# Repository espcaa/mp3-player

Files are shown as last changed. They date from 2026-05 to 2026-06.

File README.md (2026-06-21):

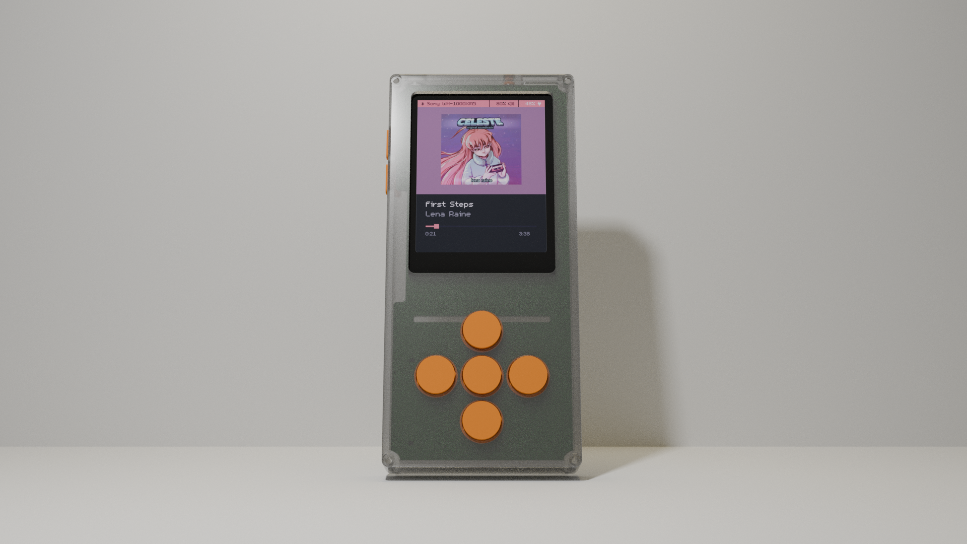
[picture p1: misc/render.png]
render


[{BOM}](https://github.com/espcaa/mp3-player/blob/main/BOM.md) - [{JOURNAL}](https://github.com/espcaa/mp3-player/blob/main/JOURNAL.md) - [{PCB}](https://kicanvas.org/?repo=https%3A%2F%2Fgithub.com%2Fespcaa%2Fmp3-player%2Ftree%2Fmain%2Fsrc%2Fkicad) - [{FIRMWARE}](https://github.com/espcaa/mp3-player/blob/main/src/firmware) - [{CAD}](https://cad.onshape.com/documents/df238a6328d0735d97863cef/w/6197d36ae28a3603accb47f3/e/8dee80f336b142ce4e5ee150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)

# mp3-player

A minimalist open source pocket sized¹ mp3 player\
\
(¹ if your pocket is big enough to fit a 115mmx50mmx20mm brick)

## Why did I even build this?

I bring my phone every time, everywhere I go. My main excuse is that I need it for music, but that's not usually what ends up happening... So I built this to have a dedicated music player that I could bring with me when I don't need a phone! (mainly high school or going for a walk)\
I also wanted to learn how to design a more complex & integrated pcb!\
\
If you find this cool, you should read [the journal](https://github.com/espcaa/mp3-player/blob/main/JOURNAL.md) I kept while designing this!

## Overview

**Specs**:

- mcu: rp2350b
- bluetooth module: fsc-BT1114QI
- dac: PCM5102A
- power: 505050 battery + BQ24075 power path ic
- pcb: 4 layer (signal, ground, power, signal) 115mmx50mm
- case: 3d printed

**Features**:

- full size sdcard slot
- 2.8 inch high definition color display (480x640, around 286 dpi)
- custom themes
- 3.5mm headphone jack
- bluetooth le + classic support
- modern and clean ui

## Hardware

<p>
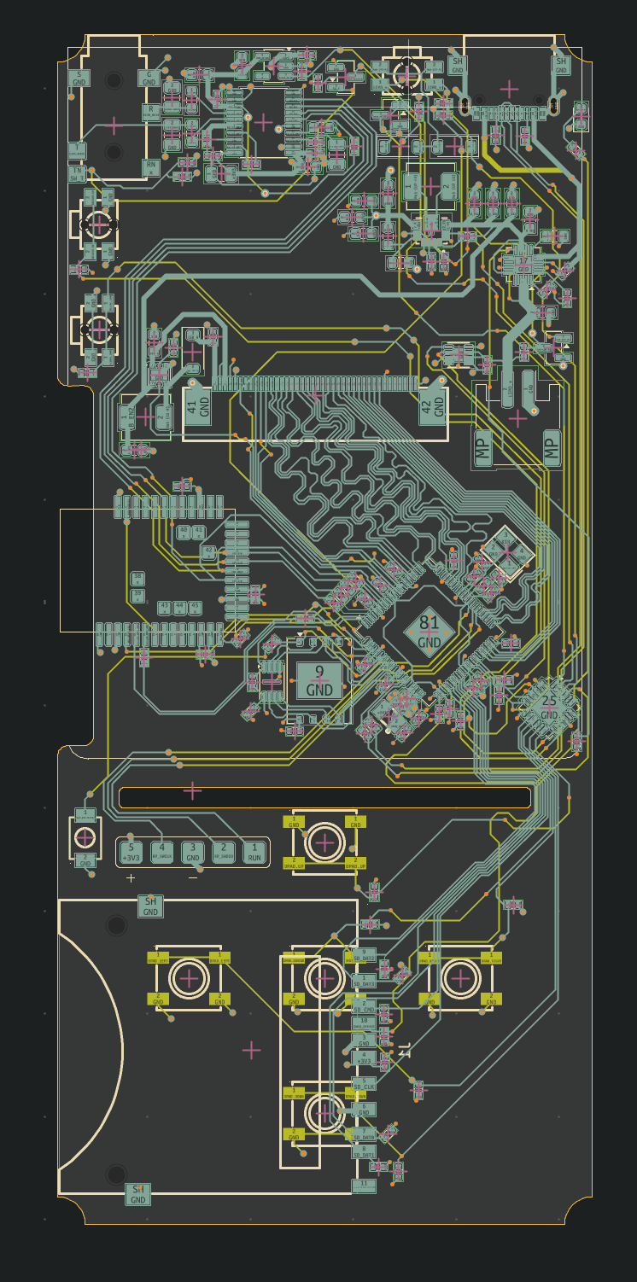
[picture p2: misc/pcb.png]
pcb
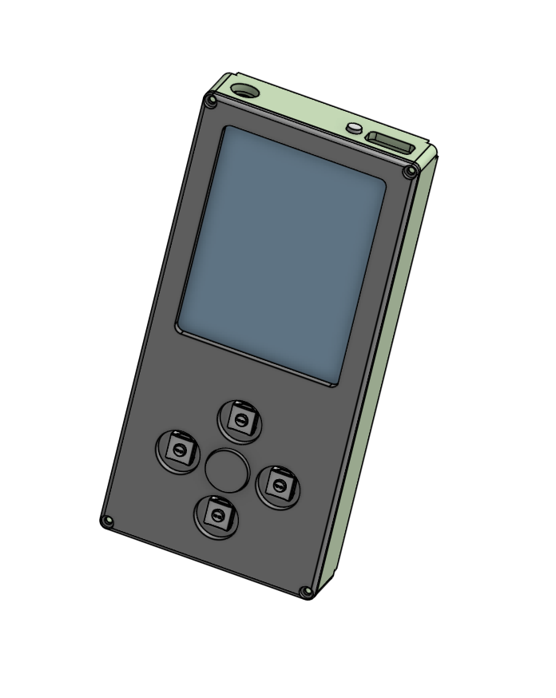
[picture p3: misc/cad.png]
cad

</p>

_pcb & cad screenshots_
\
\
The brain is a 4 layer hand routed pcb, designed to be compact & cheap to manufacture (jlcpcb 4 layers basic tolerances).\
I first planned to use a nrf chip for the audio but finally moved to a feasycom module to support classic A2DP bluetooth audio (basically everything that is not recent/high end) because I realized my headphones were not le compatible (but now my new ones are!).\
Full size sdcard support is because I wanted to be able to use my mac's sdcard reader to easily transfer new music + not lose super small micro sd cards.\
I also originally wanted to make the case in transparent resin, but I ended up choosing 3d printing for multiple reasons:

- way cheaper
- faster to iterate on
- petg is way more shock resistant than resin
- faster to get a finished project

[explore the board & schematics in your browser](https://kicanvas.org/?repo=https%3A%2F%2Fgithub.com%2Fespcaa%2Fmp3-player%2Ftree%2Fmain%2Fsrc%2Fkicad)

## Firmware

_warning: this is a wip and some parts of the firmware have been ai generated to get a poc working quickly, but I plan to rewrite it very soon._ \
\
The firmware is written in c and uses the pico sdk. I also wrote a desktop simulator that allows you to test ui changes without reflashing all the time/having the device.

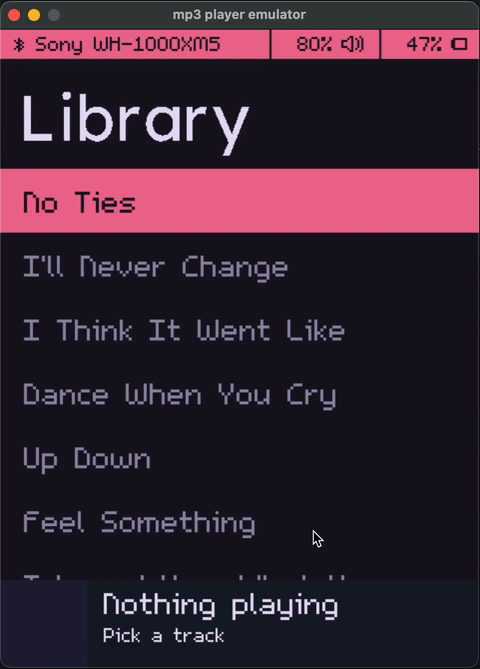
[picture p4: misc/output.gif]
firmware


**Building to run on device:**

_If you just need an already built uf2, you can just grab it from the releases page or directly from the actions tab (action runs on every commit inside src/firmware)_
\
\
(You need cmake, a pico sdk, an arm-none-eabi toolchain, pico-extras installed)

- clone this repo
- export these env vars:
  - `PICO_SDK_PATH` -> path to pico-sdk
  - `PICO_TOOLCHAIN_PATH` -> path to an arm-none-eabi toolchain (`Applications/ArmGNUToolchain/15.2.rel1/arm-none-eabi/bin` on my laptop)
  - `PICO_EXTRAS_PATH` -> path to pico-extras
- go to src/firmware/ & run `./build_pico.sh --clean`
- flash the uf2 via usb (hold BOOTSEL while plugging in the device, then drag the uf2 to the mounted drive)

**Building to run on desktop:**

_(this allows you to run/test the same ui on your computer without flashing the device!)_\
_(you need sdl2 installed)_

- go to src/firmware/ & run `./run_emulator.sh --clean`

## License

Firmware is MIT, hardware is CERN-OHL-S, and the 3d files + docs are CC-BY-SA.\
See [LICENSE](LICENSE) for details.\
\
\
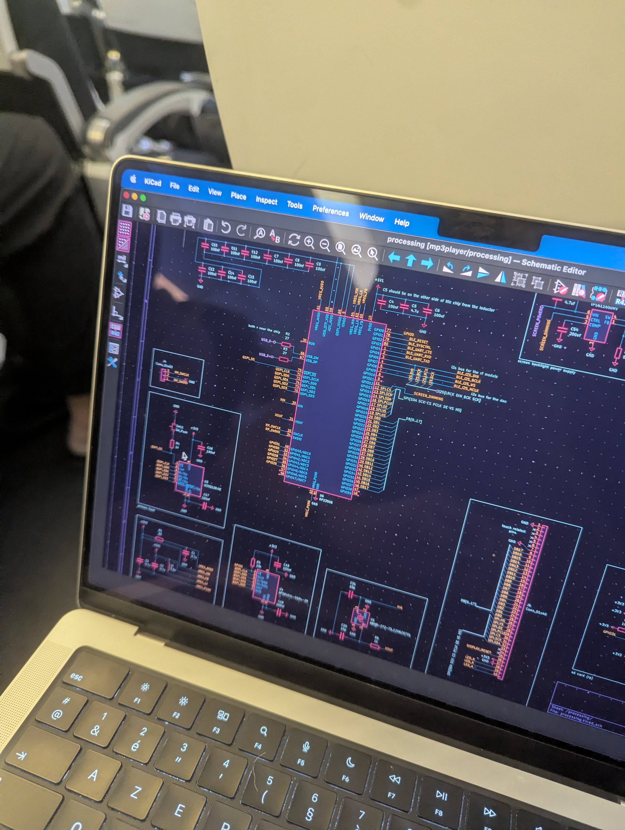
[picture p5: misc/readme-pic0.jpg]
readme-pic0

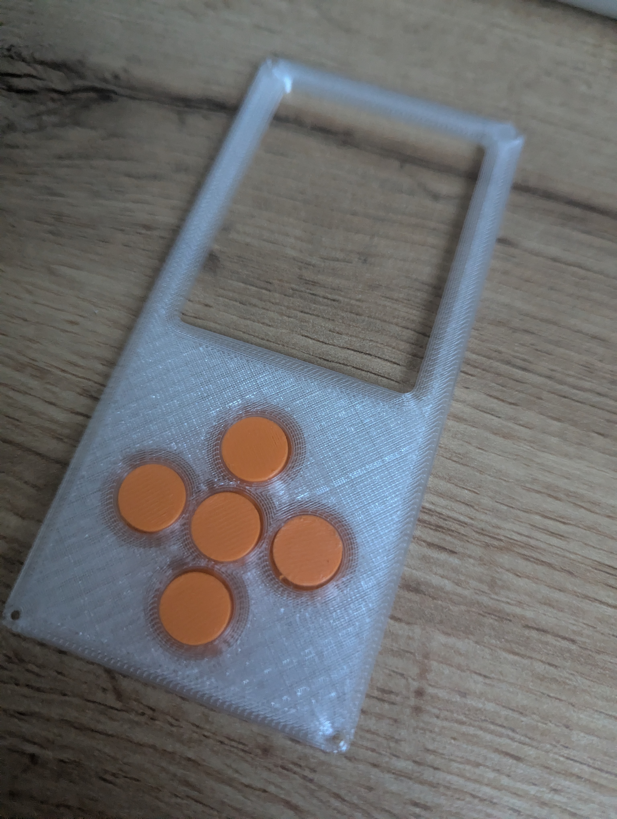
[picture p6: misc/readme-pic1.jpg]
readme-pic1

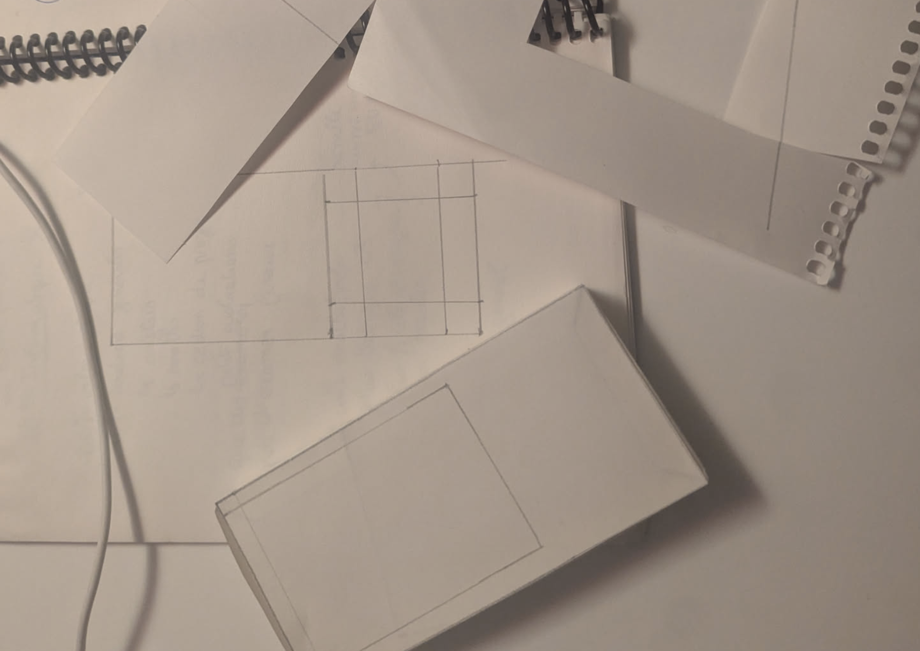
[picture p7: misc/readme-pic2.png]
readme-pic2

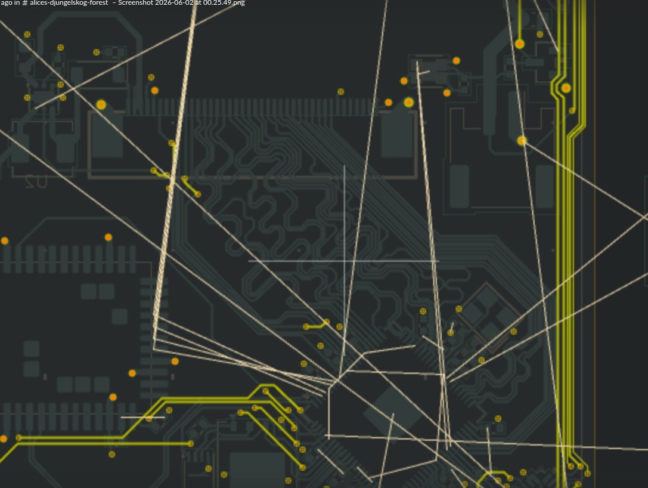
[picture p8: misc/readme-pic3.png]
readme-pic3

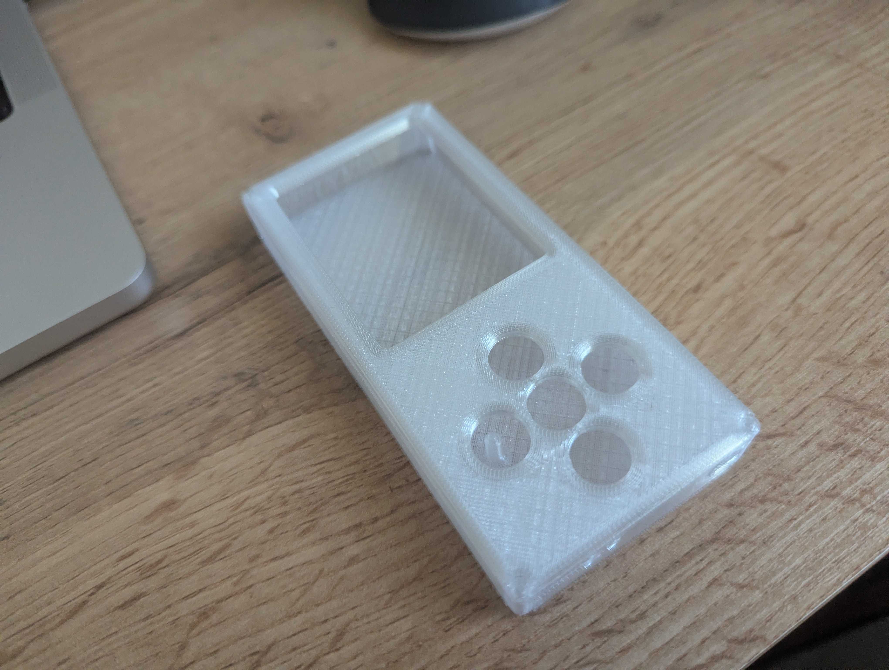
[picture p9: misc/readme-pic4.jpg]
readme-pic4


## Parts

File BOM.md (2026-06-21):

| Item | Quantity | Note/Desc | Price  | Total  |
| --- | --- | --- | --- | --- |
| 3d printed case  | 1 | PETG+PLA at $20/kg (bambulab prices) | $1 | $1 |
| pcb | 1 | jlcpcb 4 layers white + stencil (delivery to france) | $64.75 | $64.75 |
| pcb components | 1 | lcsc order (delivery to france) | $60.13 | $60.13 |
| bluetooth module | 1 | feasycom fsc-bt1114qi | $19.89 | $7.5 |
| battery | 1 | 505050 li-ion | $10.58 | $10.58 |
| screen | 1 | 2.8 inch 480x640 tft display | $15.63 | $15.63 |
| jst connectors | 1 | random aliexpress kit, only needed if your battery doesn't come with one | $1 | $1 |
| m2 1.6cm screw | 4 | // | $0.1 | $0.4 |
| m2 nut | 4 | // | $0.1 | $0.4 |
| rp2350b | 2 | only needed because lcsc doesn't have rp2350b in stock right now | $0.5 | $13.77 |

Total: around 175 usd\
\
**Specific components:**

- bluetooth module: [fsc-bt1114qi](https://www.feasycom.com/product/fsc-bt1114qi/)
- screen: [gooddisplay 2.8 inch 480x640 tft](https://www.buydisplay.com/bar-type-2-8-inch-480x640-ips-tft-lcd-display-spi-rgb-interface)

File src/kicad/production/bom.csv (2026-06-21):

Designator | Footprint | Quantity | Value | LCSC Part #
C1, C3, C5 | 0402 | 3 | 4.7u | C23733
C10, C11, C12, C13, C14, C15, C16, C19, C22, C27, C32, C4, C43, C44, C46, C47, C51, C56, C6, C7, C8, C9 | 0402 | 22 | 100nf | C1525
C2 | 0402 | 1 | 4.7u | C368809
C20, C21 | 0402 | 2 | 15p | C1548
C23, C45, C48 | 0402 | 3 | 2.2uf | C12530
C24, C25, C29, C42, C55 | 0402 | 5 | 1uf | C307427
C26, C31, C33, C37, C38, C49, C50 | 0603 | 7 | 10uf | C96446
C28, C30, C41, C53 | 0603 | 4 | 4.7uf | C19666
C34, C35, C36 | 0603 | 3 | 22uf | C59461
C39, C40 | 0805 | 2 | 2.2nf | C28260
C52, C57 | 0805 | 2 | 10uf | C1713
C54 | 0402 | 1 | 200nf | C16772
D1 | D_SOD-123 | 1 | MBR0540T1G | C21353
D2, D3 | D_SOD-123 | 2 | D_Schottky | C8598
D4 | 0603 | 1 | LED | C2286
J1 | SD-SMD_SD-006M | 1 | SD_Card_Receptacle | C125615
J2 | USB-C-SMD_GT-USB-7047C | 1 | USB_C_Receptacle_USB2.0_16P | C963218
J5 | JST_PH_S2B-PH-SM4-TB_1x02-1MP_P2.00mm_Horizontal | 1 | Conn_01x02 | C295747
J6 | FPC-SMD_AFC07-S40FCC00 | 1 | Conn_01x42 | C11062
J7 | AUDIO-SMD_PJ-342-141 | 1 | AudioJack3_Ground_SwitchTR | C7507452
L1 | IND-SMD_L2.0-W1.6_AOTA-B201610S3R3-101-T | 1 | 3.3u | C42411119
L2 | L_Sunlord_MWSA0402S | 1 | 1.5uh | C351088
L3 | L_TechFuse_SL0420 | 1 | 10uh | C22463809
Q2, Q3, Q4 | SOT-23 | 3 | BSS138 | C52895
R1, R32, R33, R38, R48, R49, R50 | 0402 | 7 | 33 | C2906931
R10, R11, R12, R17, R18, R22, R25, R27, R28, R29, R31, R35, R39, R40, R41, R42, R43, R44, R45, R46, R47, R5, R7, R8, R9 | 0402 | 25 | 10k | C2906861
R13, R14 | 0402 | 2 | 5.1k | C852856
R15 | 0603 | 1 | 820 | C23253
R16, R4, R6 | 0402 | 3 | 1k | C852624
R19, R26, R30 | 0402 | 3 | 100k | C481918
R2, R3 | 0402 | 2 | 27 | C25105
R20 | 0603 | 1 | 470k | C2907040
R21 | 0603 | 1 | 150k | C326734
R23, R24 | 0603 | 2 | 470 | C218042
R34 | 0603 | 1 | 6.8 | C2907056
R36, R37 | 0402 | 2 | 4.7k | C2906941
R51 | 0402 | 1 | 330 | C71626
SW1, SW10, SW7 | KEY-SMD_4P-L4.7-W3.5-P1.70-LS6.4-EH | 3 | EVQPUL02K | C79175
SW11 | SW-SMD_L3.9-W3.0-P4.45 | 1 | TS-1088-AR02016 | C720477
SW3, SW4, SW5, SW8, SW9 | SW-SMD_4P-L6.2-W6.2-P4.00-LS6.8 | 5 | SW_Push | C115354
U1 | CRYSTAL-SMD_4P-L3.2-W2.5-BL | 1 | ABM8-272-T3_C20625731 | C20625731
U10 | SOT-23-5 | 1 | LP5907MFX-3.3 | C23380874
U11 | WSON-6-1EP_2x2mm_P0.65mm_EP1x1.6mm | 1 | TPS61165DRV | C122568
U12 | WQFN-24-1EP_4x4mm_P0.5mm_EP2.45x2.45mm | 1 | TCA9555RTWR | C140277
U3 | WSON-8-1EP_8x6mm_P1.27mm_EP3.4x4.3mm | 1 | W25Q128JVE | C2456297
U4 | Winbond_USON-8-1EP_3x2mm_P0.5mm_EP0.2x1.6mm | 1 | APS6404L-SQRx-ZR | C3040877
U5 | TSSOP-20_4.4x6.5mm_P0.65mm | 1 | PCM5102A | C107671
U6 | QFN-80-1EP_10x10mm_P0.4mm_EP3.4x3.4mm | 1 | RP2350B | C42415655
U7 | VREG_TPS63070RNMR | 1 | TPS63070RNMR | C109322
U8 | VQFN-16-1EP_3x3mm_P0.5mm_EP1.6x1.6mm | 1 | BQ24075RGT | C15464
U9 | SON50P200X200X80-9N | 1 | MAX17048G_T10 | C2682616

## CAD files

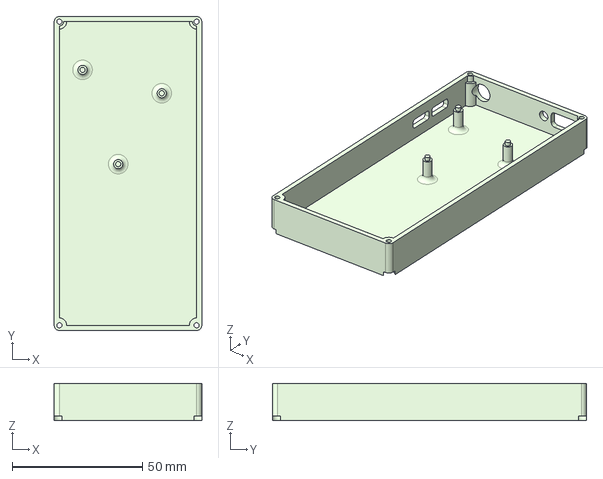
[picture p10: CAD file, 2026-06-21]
src/cad/bottom.step
56.6 x 120.3 x 14.3 mm

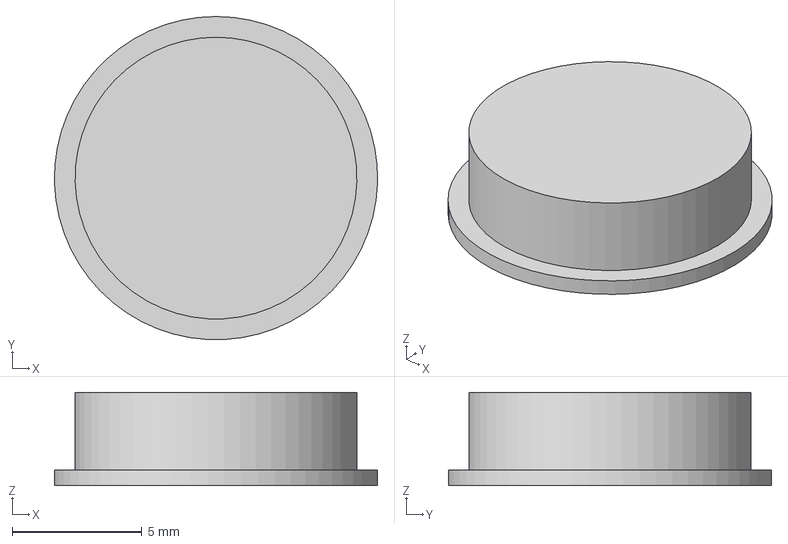
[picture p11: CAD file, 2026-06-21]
src/cad/buttons/dpad.step
12.5 x 12.5 x 3.60 mm

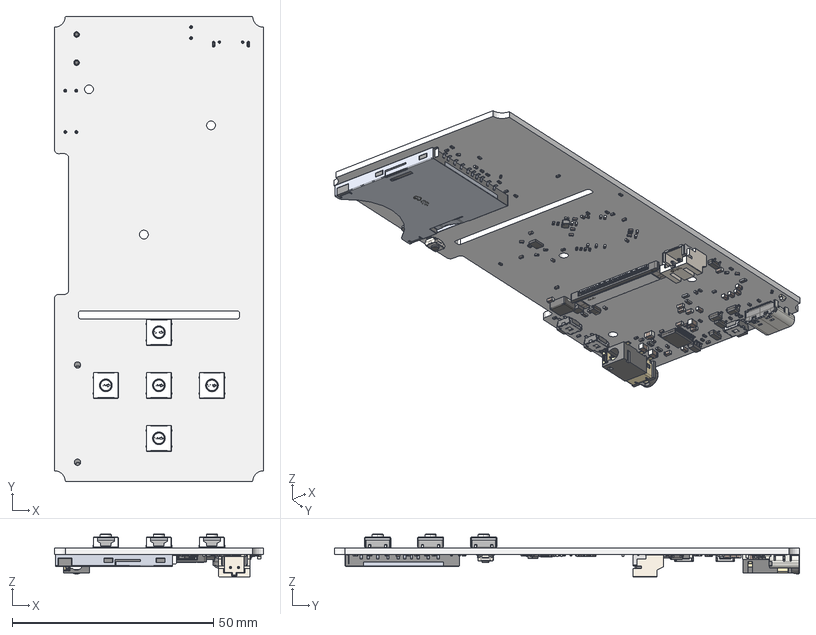
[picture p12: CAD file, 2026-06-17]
src/kicad/pcb.step
52.0 x 115.7 x 10.6 mm
SW-SMD_4P-L6.2-W6.2-H3.4-P4.00-LS6.8 x 5
R_0402_1005Metric x 45
C_0603_1608Metric x 14
KEY-SMD_4P-L4.7-W4.5-H1.7-LS6.4-P1.7 x 3
C_0402_1005Metric x 37
IND-SMD_L2.0-W1.6_AOTA-B201610S3R3-101-T
R_0603_1608Metric x 6
SOT-23 x 3
SOT-23-5
TSSOP-20_4.4x6.5mm_P0.65mm
FPC-SMD_AFC07-S40FCC00
C_0805_2012Metric x 4
USB_C_Receptacle_GCT_USB4105-xx-A_16P_TopMnt_Horizontal
SD-SMD_SD-006M
CONN-SMD_P2.00_S2B-PH-SM4-TB-LF-SN
D_SOD-123 x 3
WSON-6-1EP_2x2mm_P0.65mm_EP1x1.6mm
LED_0603_1608Metric
SW-SMD_L3.9-W2.9-H2.0-LS4.8
L_TechFuse_SL0420
AUDIO-SMD_PJ-342-141
Winbond_USON-8-1EP_3x2mm_P0.5mm_EP0.2x1.6mm
mp3player_PCB

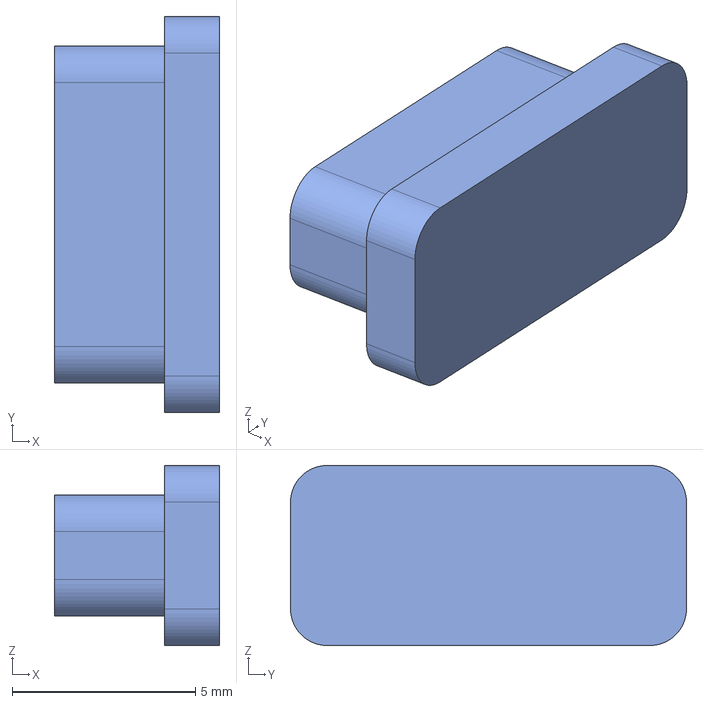
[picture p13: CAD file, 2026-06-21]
src/cad/buttons/volume.step
4.50 x 10.8 x 4.91 mm

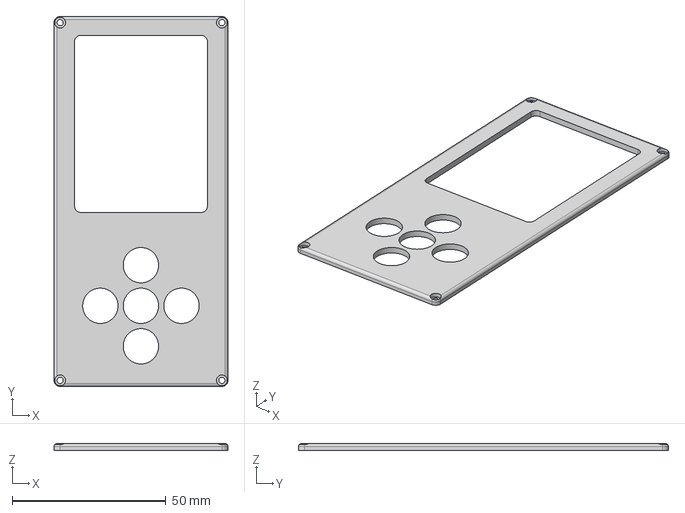
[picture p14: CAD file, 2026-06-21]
src/cad/top.step
56.6 x 120.3 x 2.20 mm

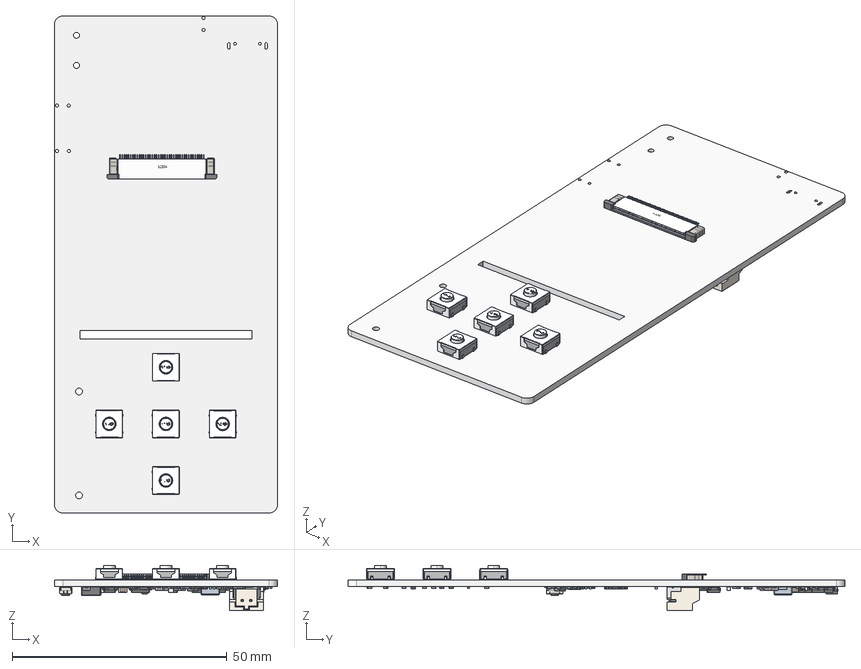
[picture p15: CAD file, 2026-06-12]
src/kicad/.step
52.0 x 115.8 x 10.6 mm
SW-SMD_4P-L6.2-W6.2-H3.4-P4.00-LS6.8 x 5
R_0402_1005Metric x 42
C_0603_1608Metric x 14
C_0402_1005Metric x 37
IND-SMD_L2.0-W1.6_AOTA-B201610S3R3-101-T
R_0603_1608Metric x 6
SOT-23 x 3
SOT-23-5
TSSOP-20_4.4x6.5mm_P0.65mm
.step 1.33.1
FPC-SMD_AFC07-S40FCC00
C_0805_2012Metric x 4
CONN-SMD_P2.00_S2B-PH-SM4-TB-LF-SN
D_SOD-123 x 3
WSON-6-1EP_2x2mm_P0.65mm_EP1x1.6mm
SW-SMD_L3.9-W2.9-H2.0-LS4.8
L_TechFuse_SL0420
Winbond_USON-8-1EP_3x2mm_P0.5mm_EP0.2x1.6mm
mp3player_PCB

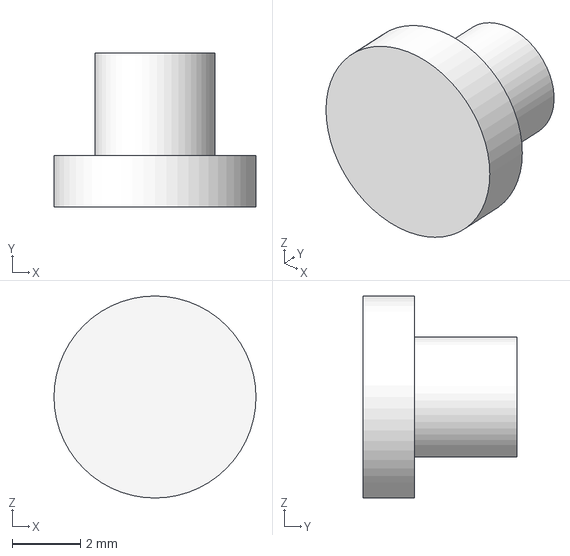
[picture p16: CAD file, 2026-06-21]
src/cad/buttons/power.step
5.90 x 4.50 x 5.90 mm

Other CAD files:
misc/render.blend

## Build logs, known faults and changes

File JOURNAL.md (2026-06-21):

## 12th May 2026

Today is the first day of this project :) \
I decided to work on this because I wanted a fun and "simple" project to work on! Okay, maybe not that simple if I keep overengineering it aaaaa \
\
Ideas:

- rp2350b to drive the display & buttons & audio output
- nrf54l1O for bluetooth
- full size sd card for storage (love them, i lost so many micro sd cards)
- spi display

Final components list: (might change a lot)

- rp2350b
- nrf54l1O
- 1.3 inch spi display
- 2.8 inch ips screen - [link](https://www.buydisplay.com/bar-type-2-8-inch-480x640-ips-tft-lcd-display-spi-rgb-interface)
- PCM5102A (i don't know anything about dacs, so this is likely to change)
- 5 buttons (dpad) + 1 for power
- 1 rotary encoder for volume control
- 1 neopixel

After that, I started working on the schematic of my pcb! So far, I followed raspberry pi's reference design to get the rp2350b working & added the sd card.\
\
Screenshots:\
\
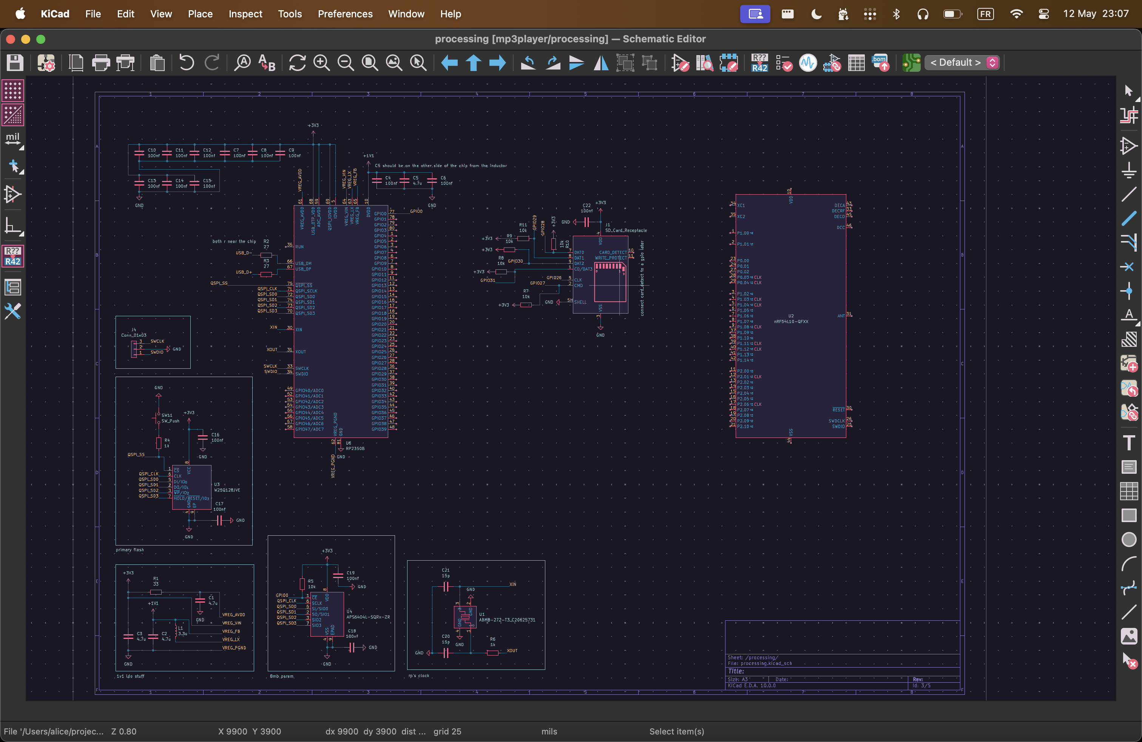
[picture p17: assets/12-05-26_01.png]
 
\
 _basic rp2350b design_
\
\
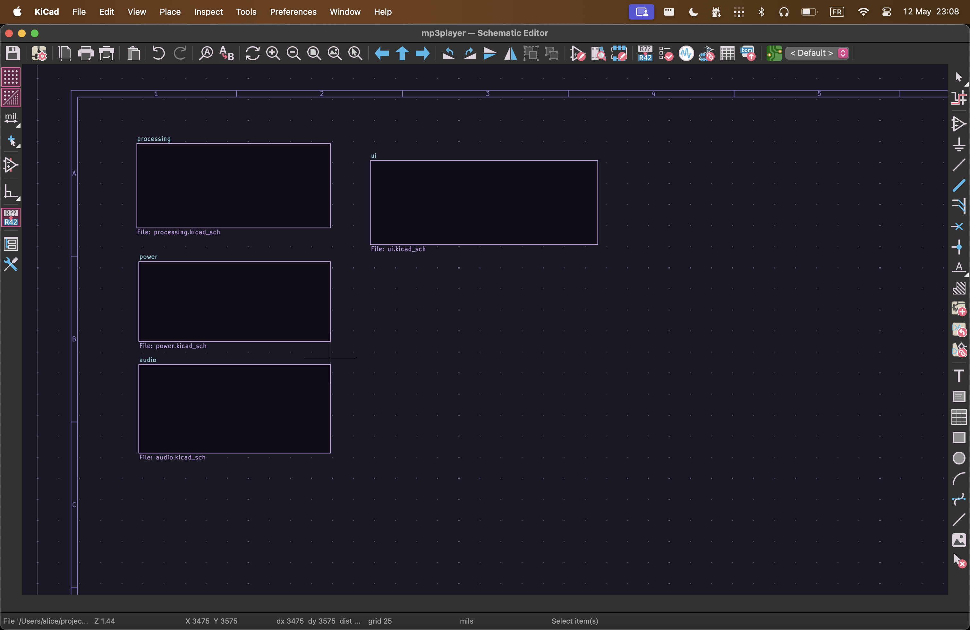
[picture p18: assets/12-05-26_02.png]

\
 _multiple sheets for different parts of the design_
\
\
 **Total time spent: 5 hours**

## 14th May 2026

I forgot to journal yesterday's progress so this is going to cover that as well.
After diving deeper in bluetooth audio, I realized that going with a nrf was maybe not that good of an idea as it only supports LE Audio. I then did some research and found the FSC-BT1114QI that support both classic bluetooth audio & LE Audio! That means I can make my player future proof & still work with most things!.\
The only problem is price, 10$ :(\
\
I then designed a basic schematic & footprint since it doesn't seem to be very popular, and added it to my design!\
\
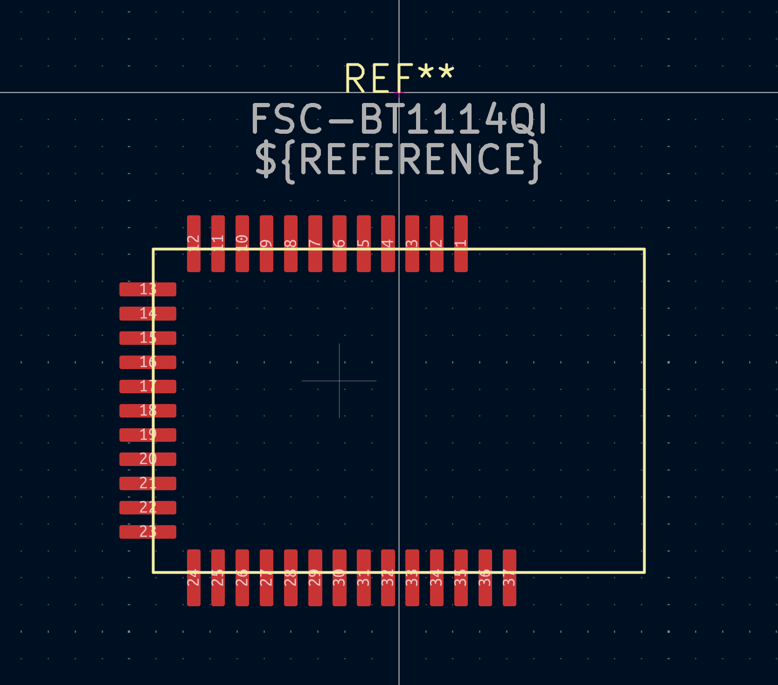
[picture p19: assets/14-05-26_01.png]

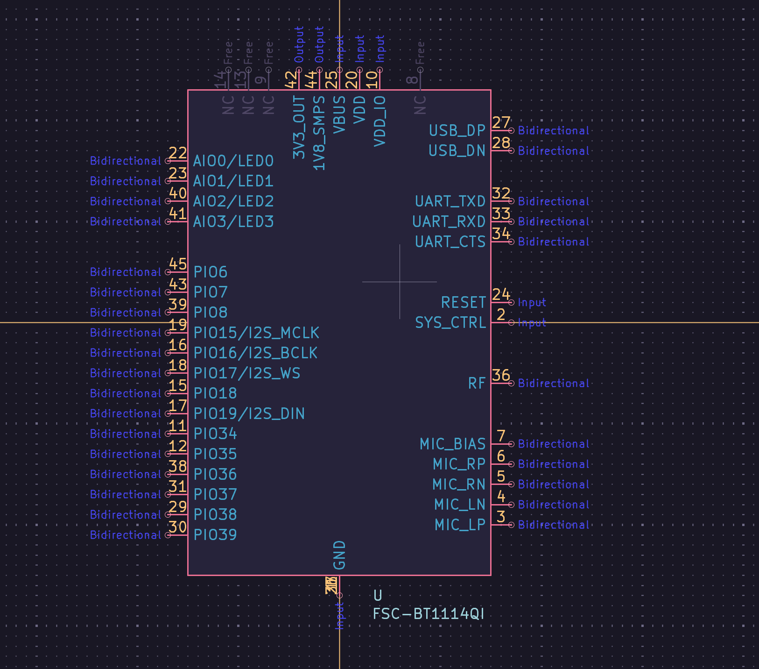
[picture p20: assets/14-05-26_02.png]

\
 _schematic & footprint for the bluetooth module_\
\
I finished the day by wiring that new module :p\
\
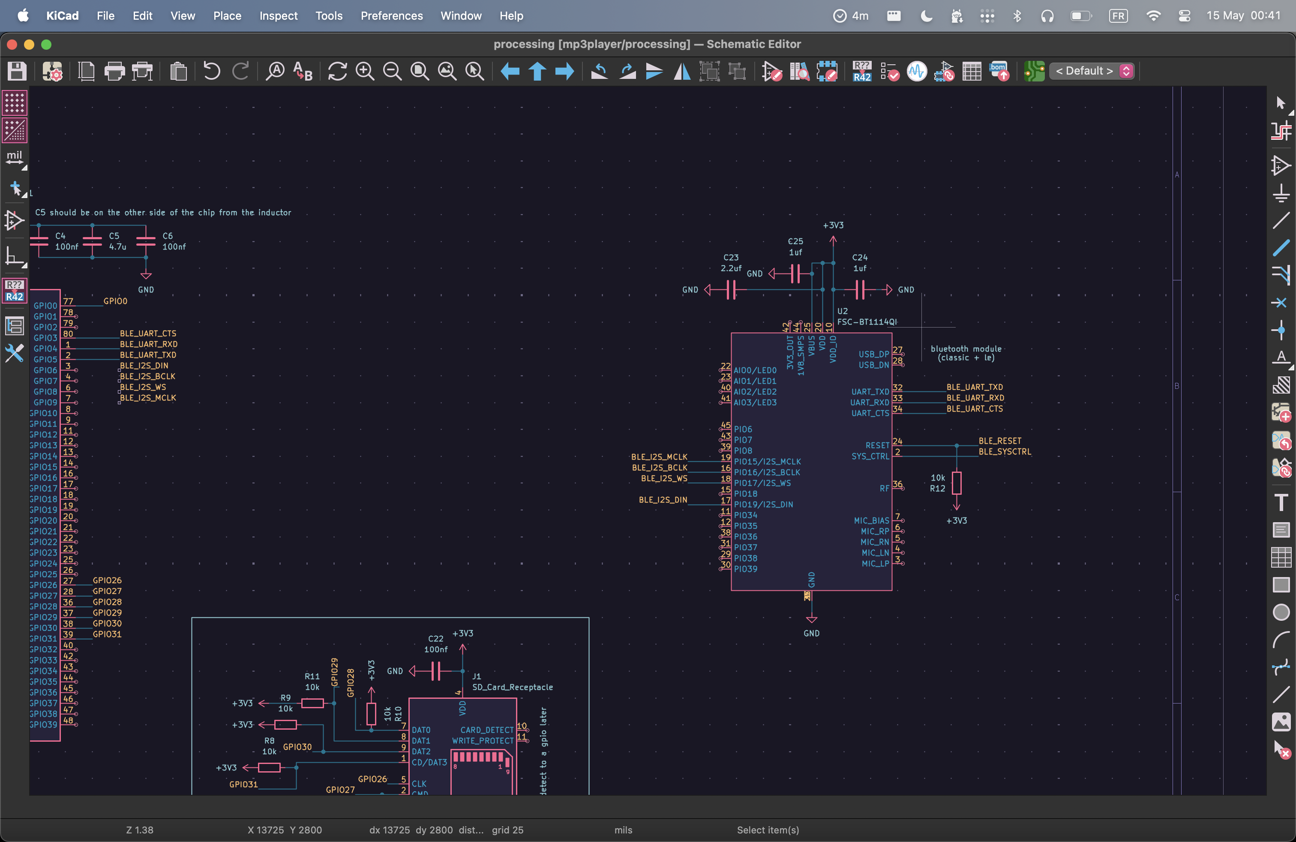
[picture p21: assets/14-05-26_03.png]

\
\
**Total time spent: 9 hours**

## 15th May 2026

Today is power management day ::: \
I first started by trying to add a DW01A to my pcb to protect the battery, but after doing some research I found out that it's not really necessary since most batteries already come with a protection circuit.\
This is what I ended up with:\

```mermaid
graph LR
    USB[USB 5V]:::source
    BATT[LiPo]:::source
    FuelGauge[Battery SOC ic]:::ic
    BQ["BQ24075 <br /> (charging and switching)"]:::ic
    Regulator[Buck-Boost<br>Converter]:::converter
    SYS[System Load]:::load

    USB --> BQ
    BATT --> FuelGauge
    FuelGauge --> BQ

    BQ -->|SYSTEM_POWER| Regulator
    Regulator -->|3V3| SYS
```

_hopefully it works :-:_\
\
wip schematic:\
\
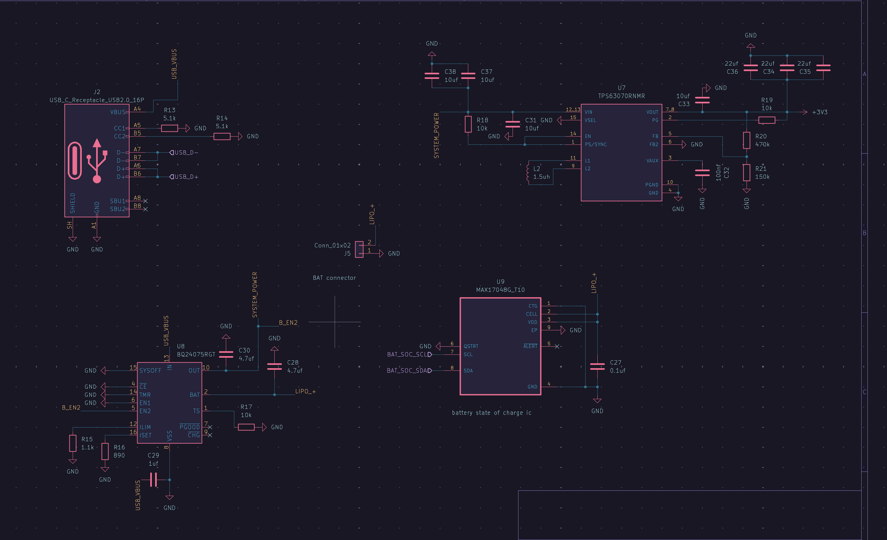
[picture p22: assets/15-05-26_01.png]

\
\
**Total time spent: 11 hours**

## 16th May 2026

Today's mission was to wire the 3.5mm jack part of the audio setup! (dac :fear:)\
I think I somehow made it and it should work? hopefully?\
\
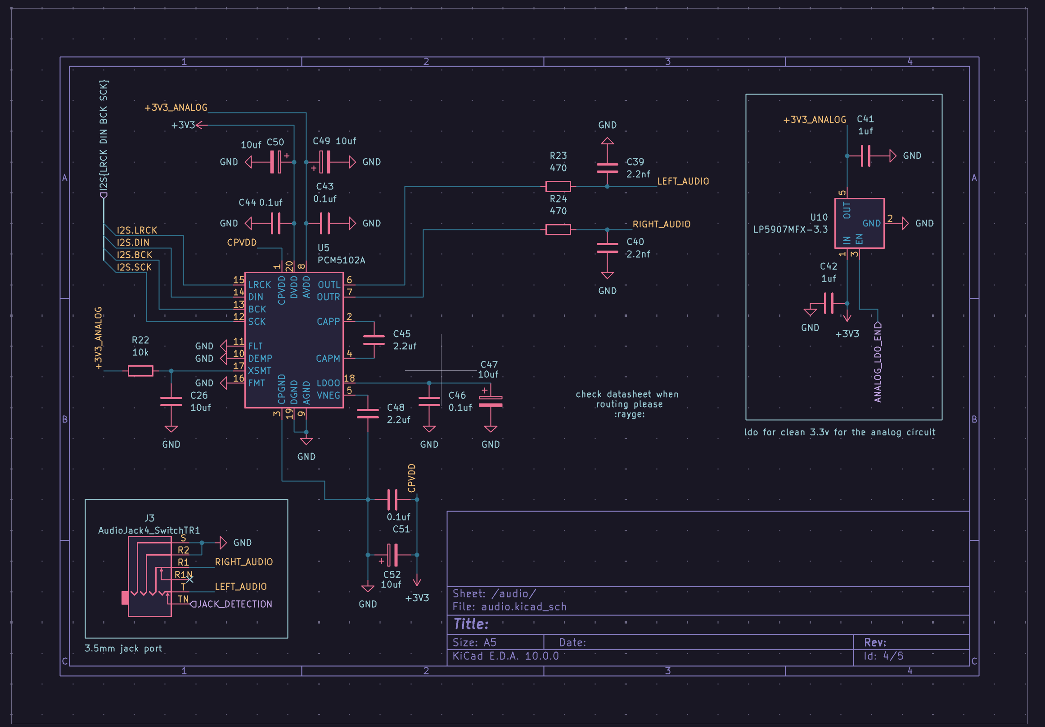
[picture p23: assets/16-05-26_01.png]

\
_schematic for the audio output (used kicad buses for the first time \o/)_\
\
I also added a power button to power on/off the device with a long/short press!\
\
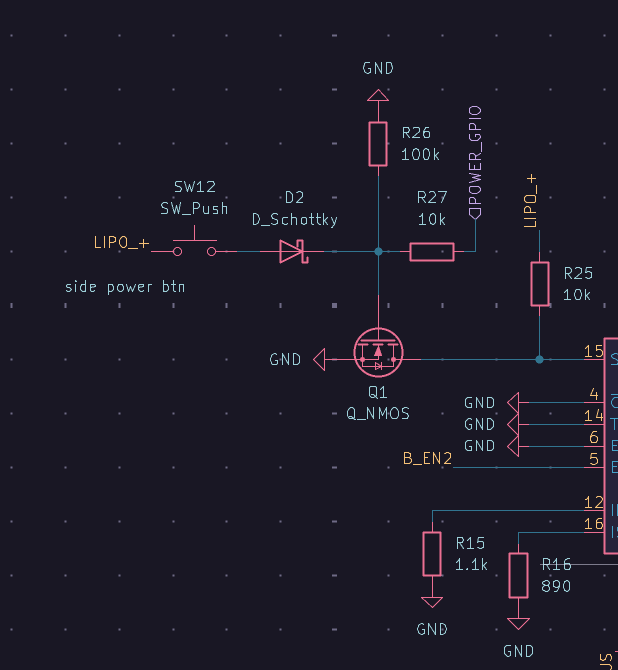
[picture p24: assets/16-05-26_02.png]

\
_schematic for the power button_\
\
& random fixes here and there\
i need to sleep noww\
\
**Total time spent: 15 hours**

## 23rd May 2026

I locked in on a transatlantic flight and made a lot of progress!

- new power latch circuit
- better hierarchical sheet structure
- more buses :D
- io expanders to fit everything
- screen wiring

\
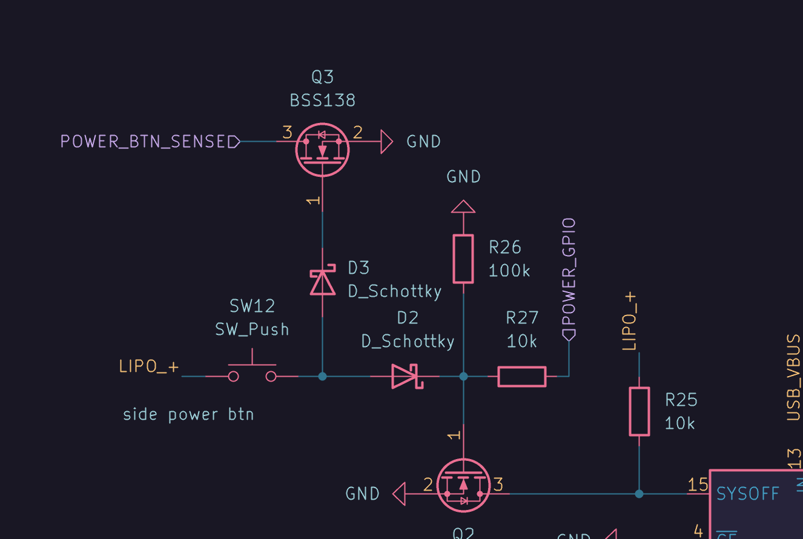
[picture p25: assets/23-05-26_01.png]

\
_power latch circuit_
\
\
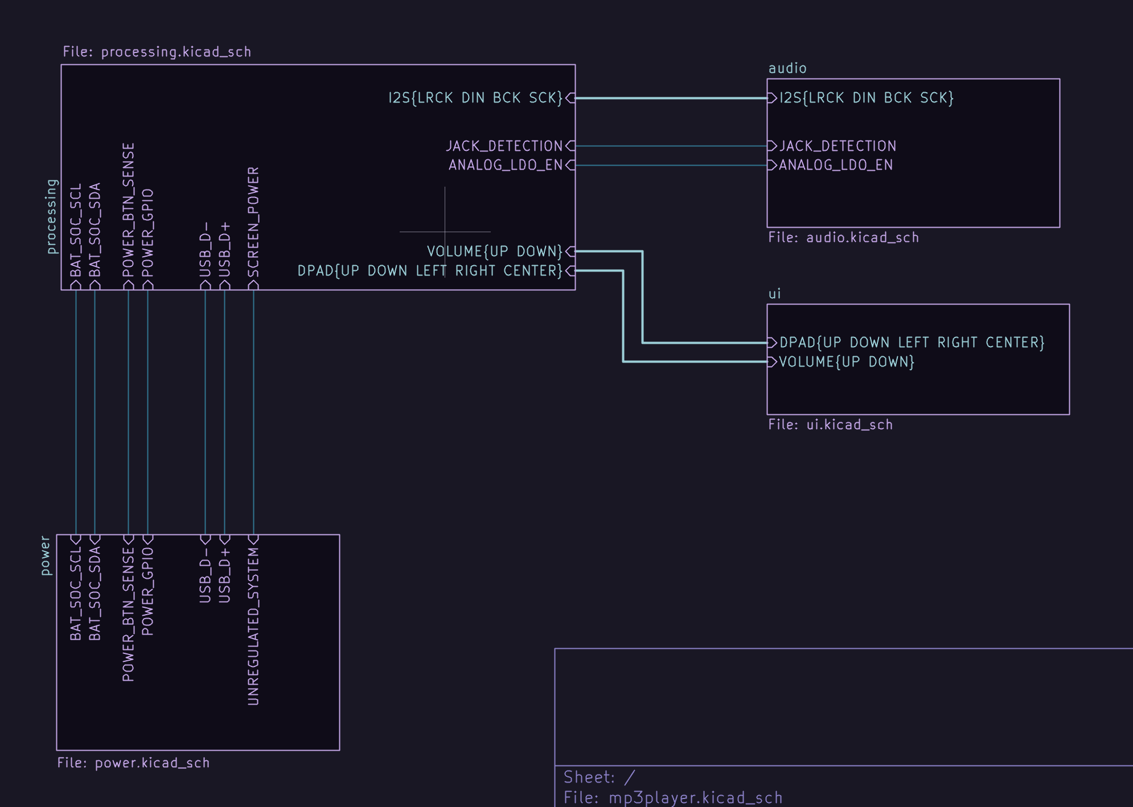
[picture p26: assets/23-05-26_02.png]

\
_hierarchical sheets_
\
\
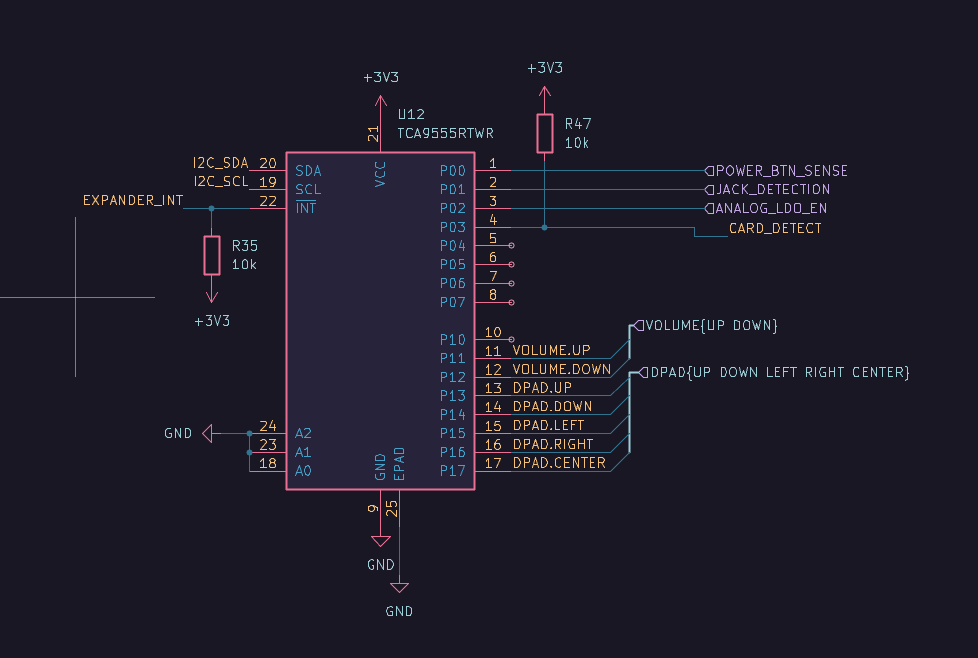
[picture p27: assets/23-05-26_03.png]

\
_io expander thingies_
\
\
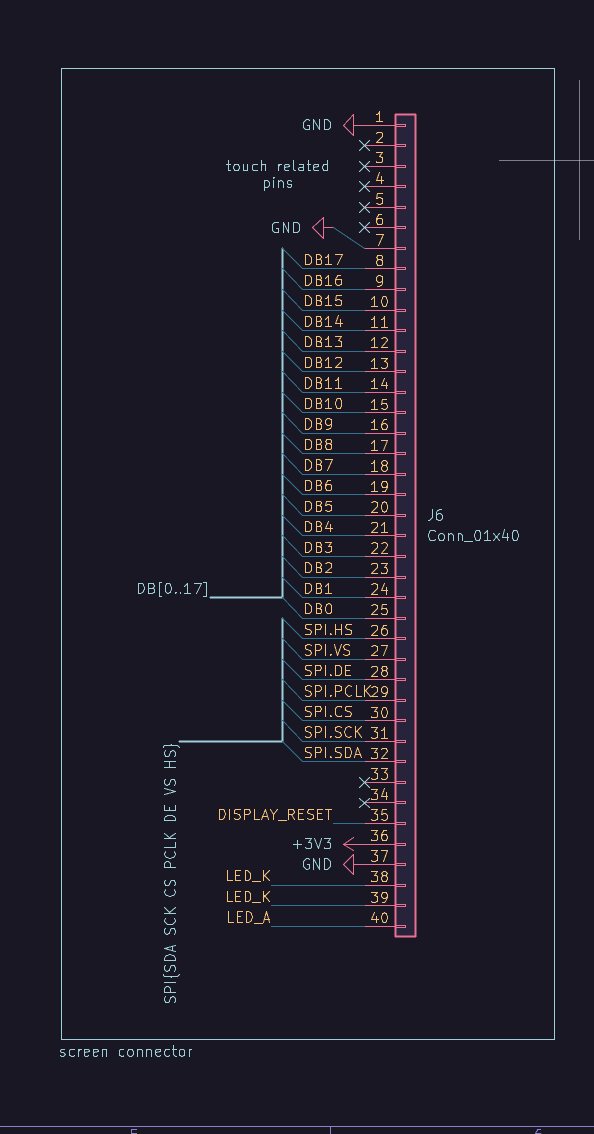
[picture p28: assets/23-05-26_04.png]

\
_screennn_
\
\
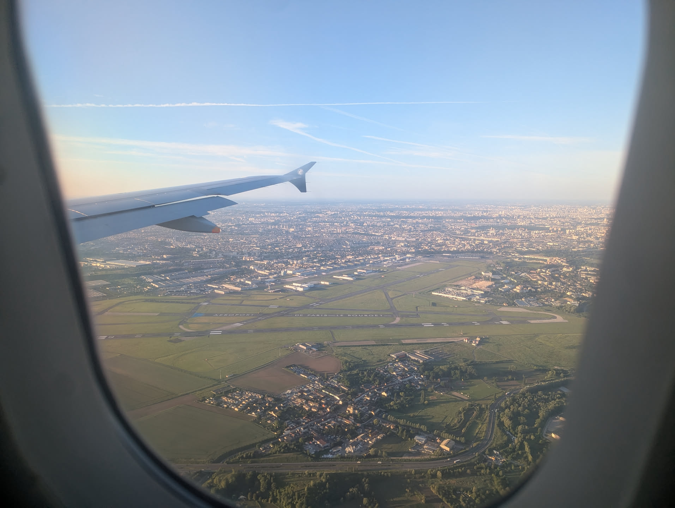
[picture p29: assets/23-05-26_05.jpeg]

\
_bonus plane picture_

**Total time spent: 21 hours**

## 28th May 2026

Today I worked on the component assignment so that I can start routing!\
I also cleaned up the schematic everywhere & added some missing stuff.\
\
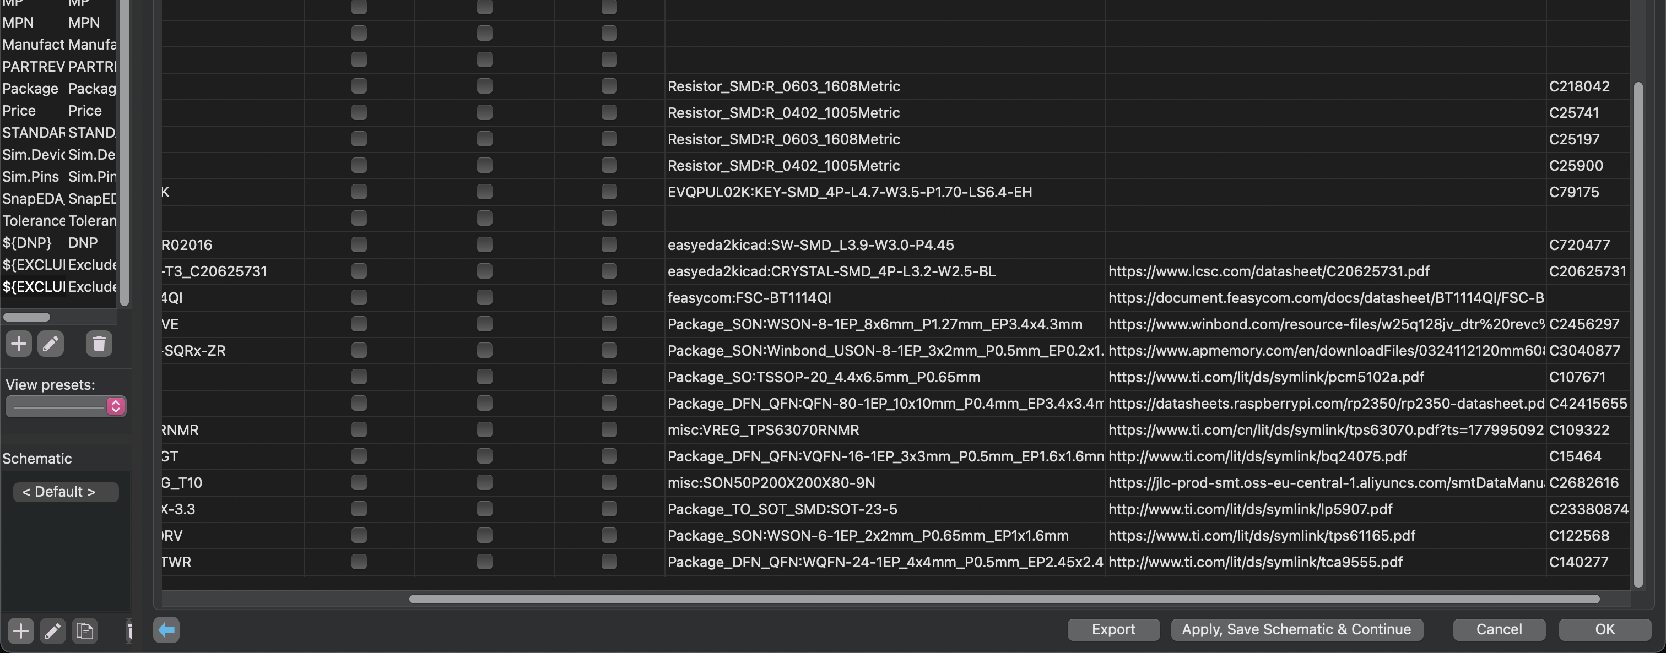
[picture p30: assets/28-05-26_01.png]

\
_component assignment_

**Total time spent: 25 hours**

## 29th May 2026

Today I fixed footprint issues & finished component assignment!\
Every component now has a footprint & a lcsc part number!!! \
\
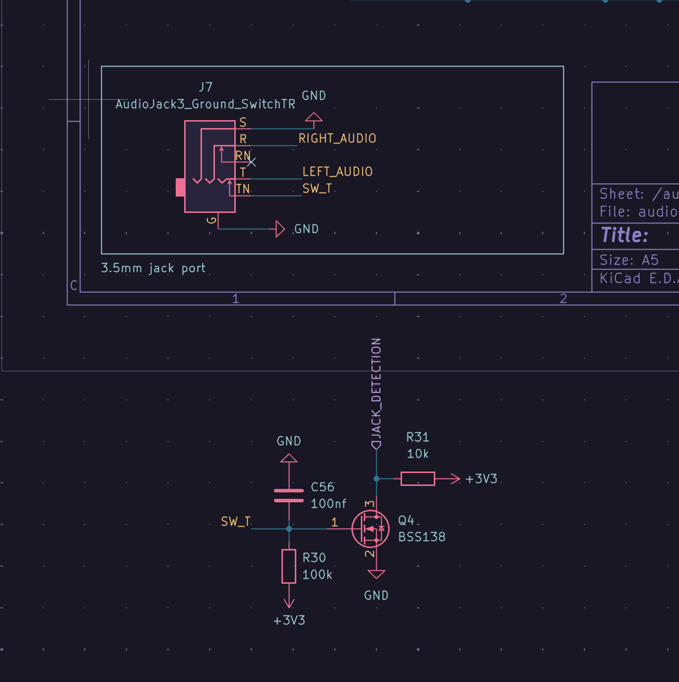
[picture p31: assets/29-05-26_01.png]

\
_new jack wiring_
\
\
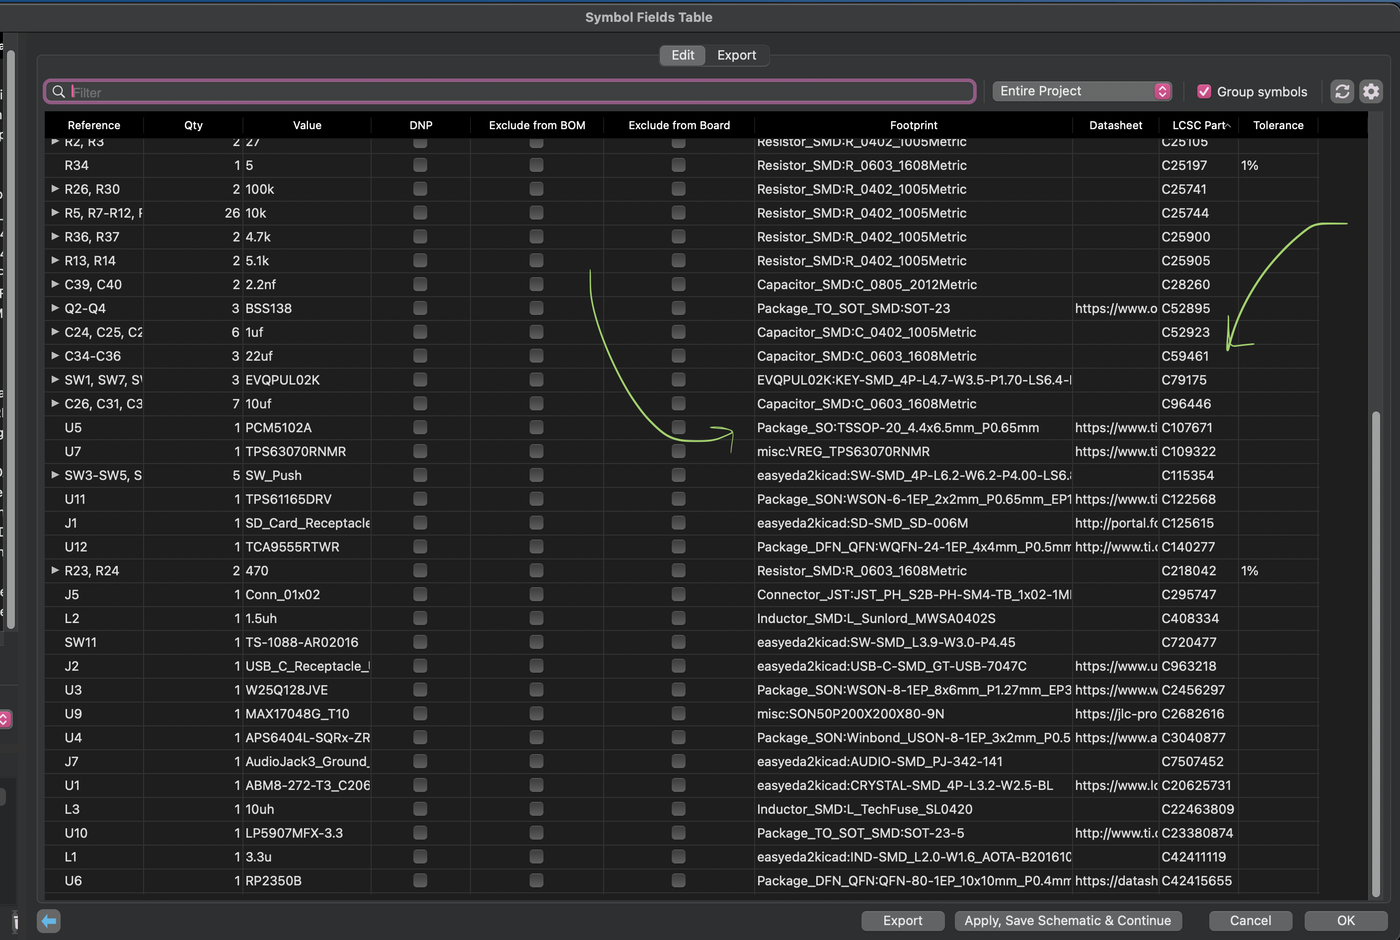
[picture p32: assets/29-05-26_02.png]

\
_component assignment done!_
\
\
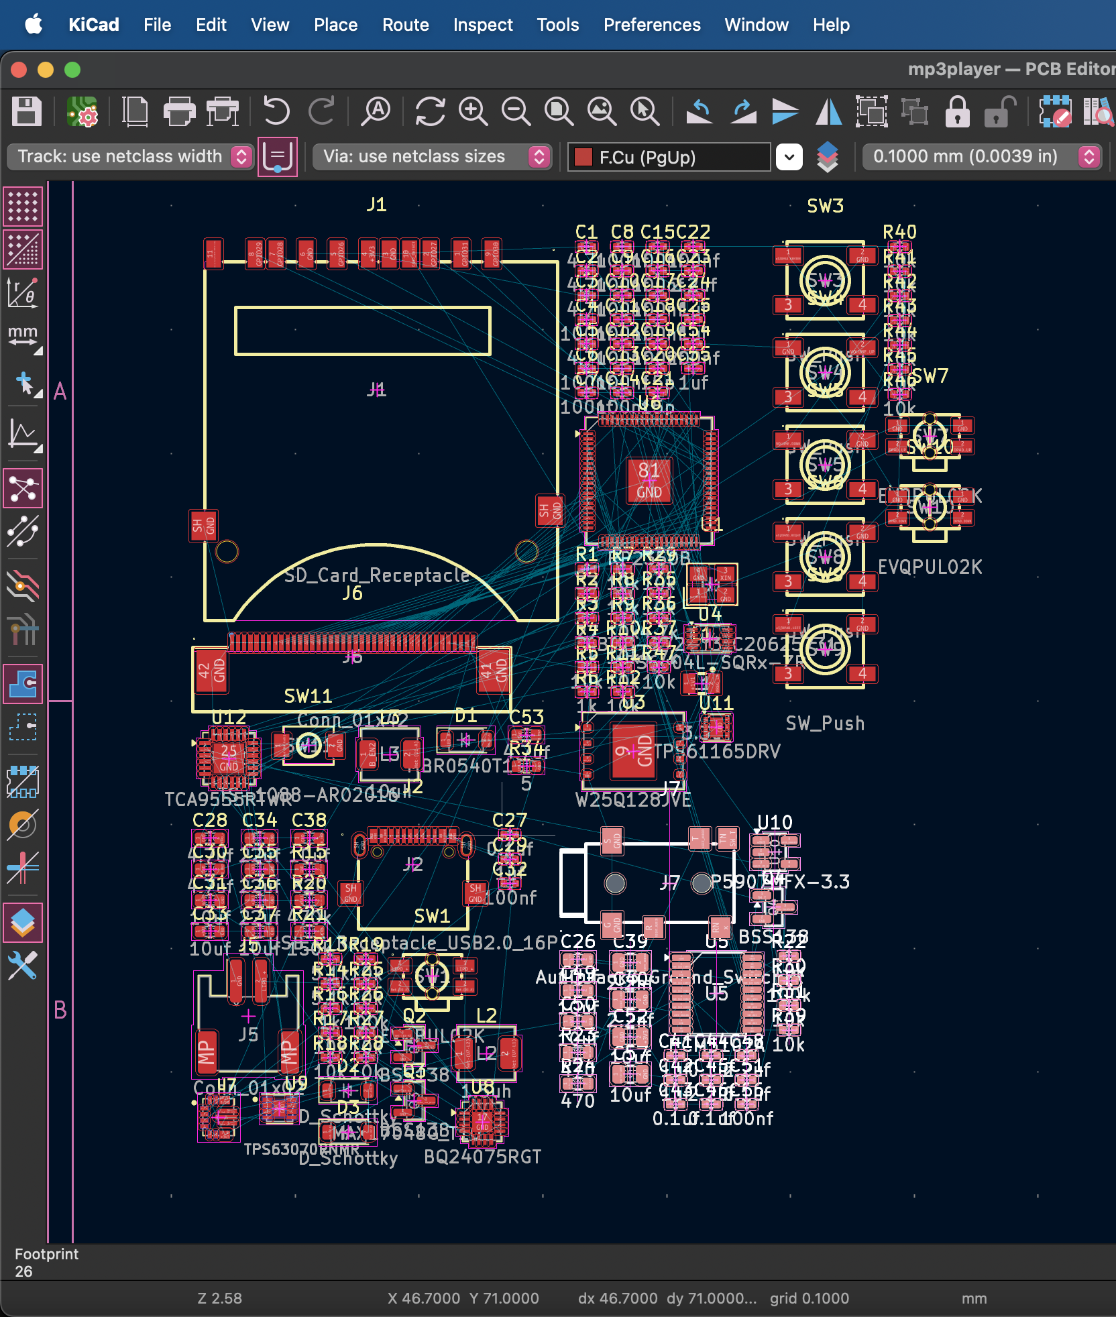
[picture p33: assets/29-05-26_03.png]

\
_ready for routing!_
\
**Total time spent: 30 hours**

## 30th May 2026

Today I started routing my pcb! Well actually the first thing I needed to do before that was to find the exact form factor I was going for.\
Paper is very useful for that!\
\
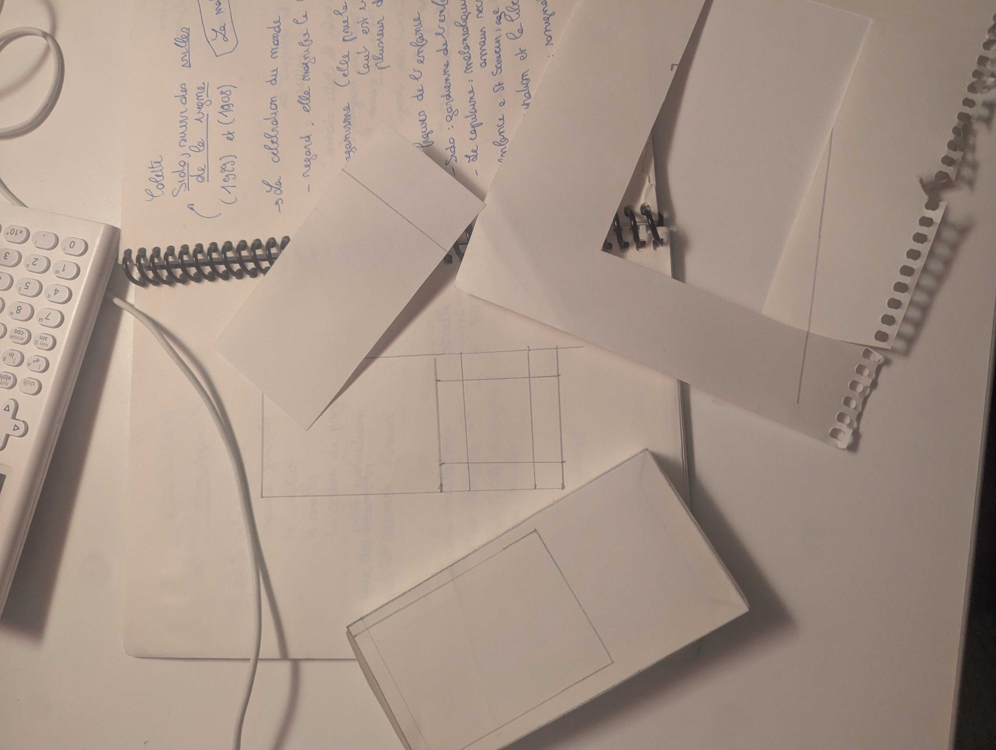
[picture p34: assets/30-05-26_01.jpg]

\
_paper prototype :p_
\
\
After that, (and a bunch of iterations, and headaches over where to place the different connectors & ports) I ended up with this:\
\
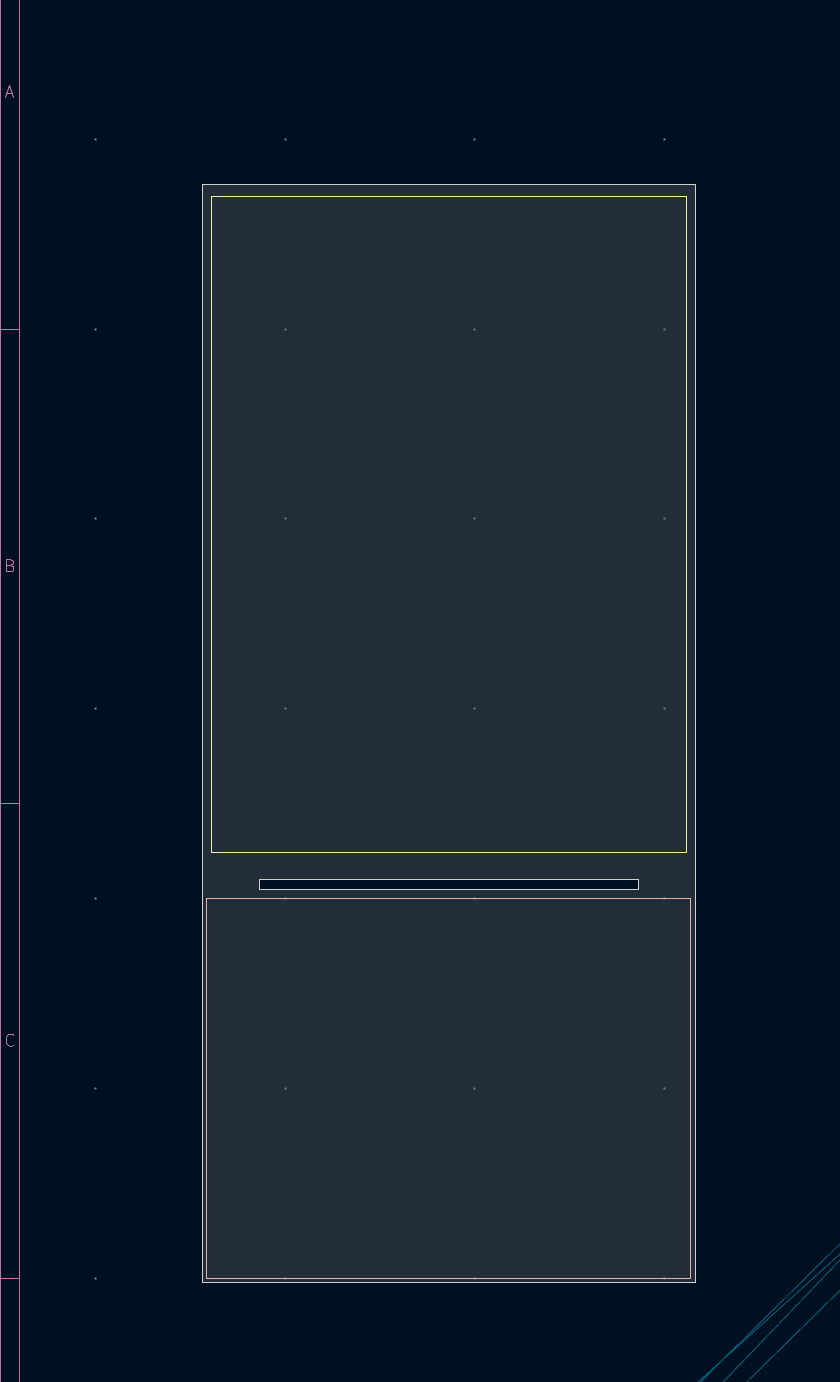
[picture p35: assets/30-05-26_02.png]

\
_device outline_
\
\
I then started routing! I first did the analog audio part (no idea why) and then moved on to the power supply.
\
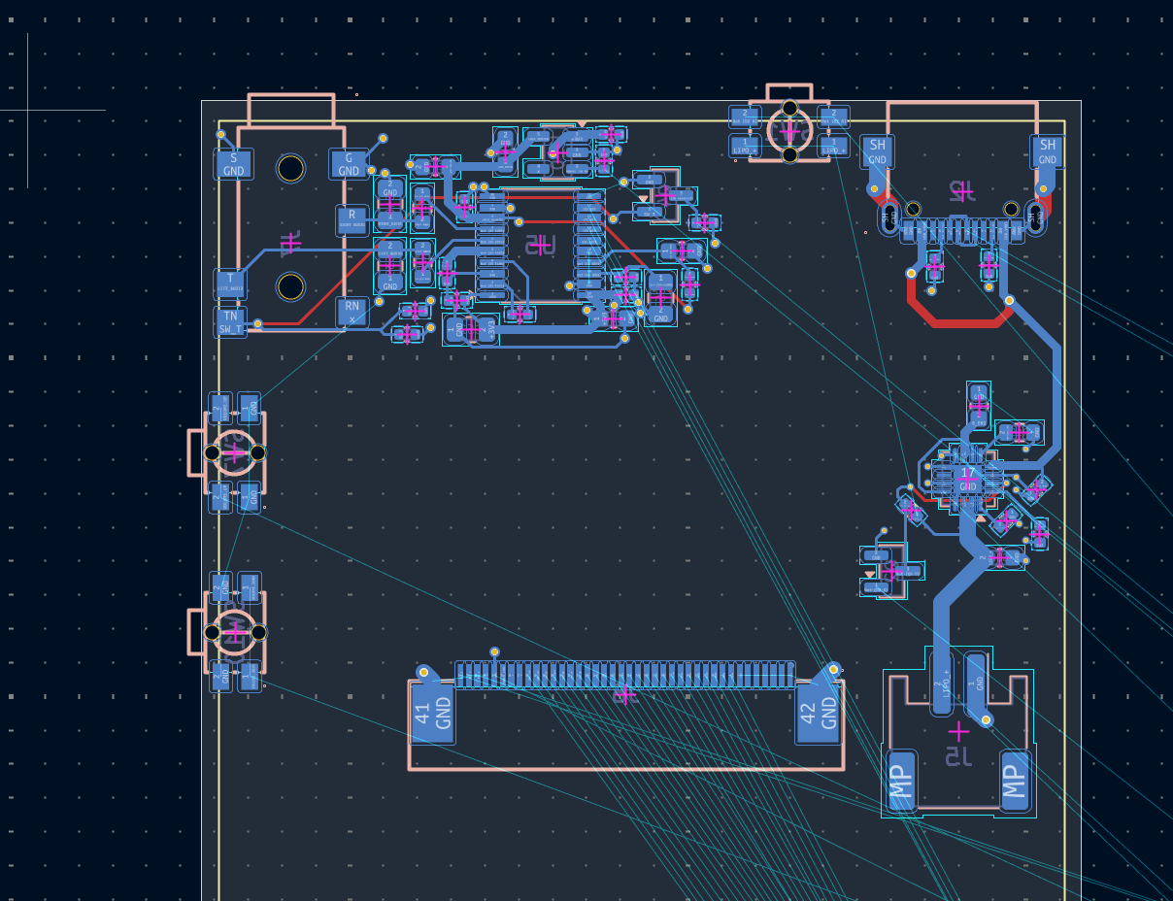
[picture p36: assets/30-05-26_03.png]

\
_routing..._  
\
I also fixed some schematic issues that I found while routing (wrong caps & inverted buses, other random things i forgot)

**Total time spent: 35 hours**

## 31st May 2026

I basically spent my day routing!\
A lot of the components moved around the board while I was trying to find the best arrangement for everything :sob:, but i think this is good enough?\
\
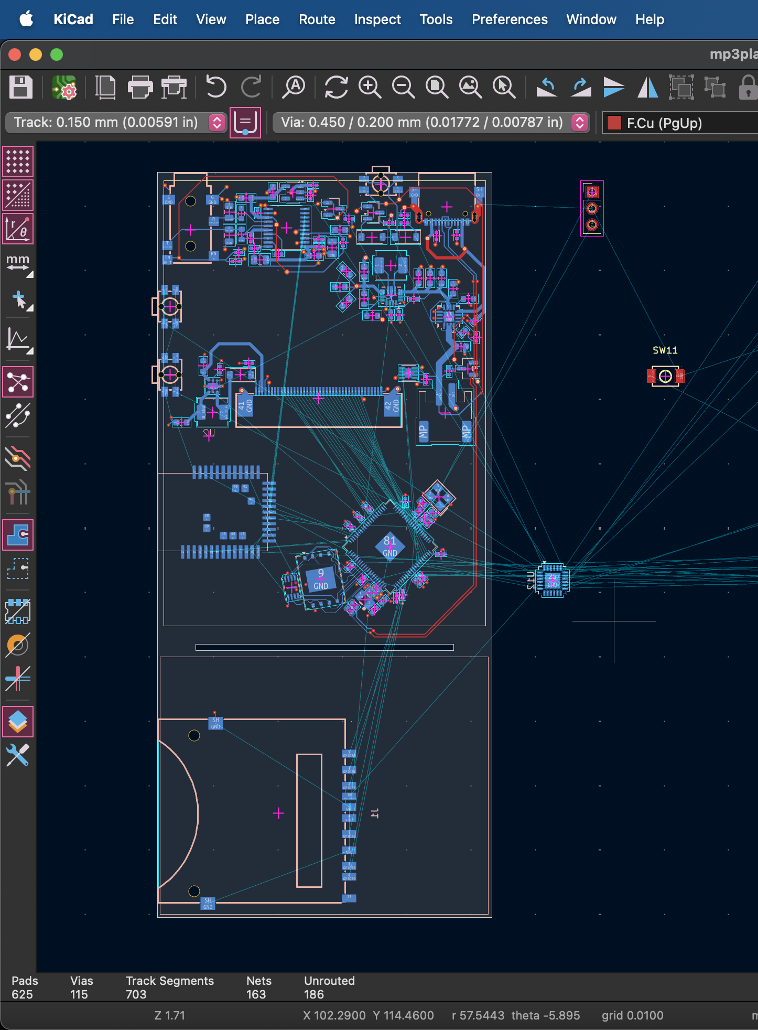
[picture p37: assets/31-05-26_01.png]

\
_routing..._
\
\
**Total time spent: 40 hours**

## 1st June 2026

June already...\
Today I continued routing the board! Did a lot of the annoying stuff (screen, sd card, spi..., dpad layout) & it's almost finished!!!\
\
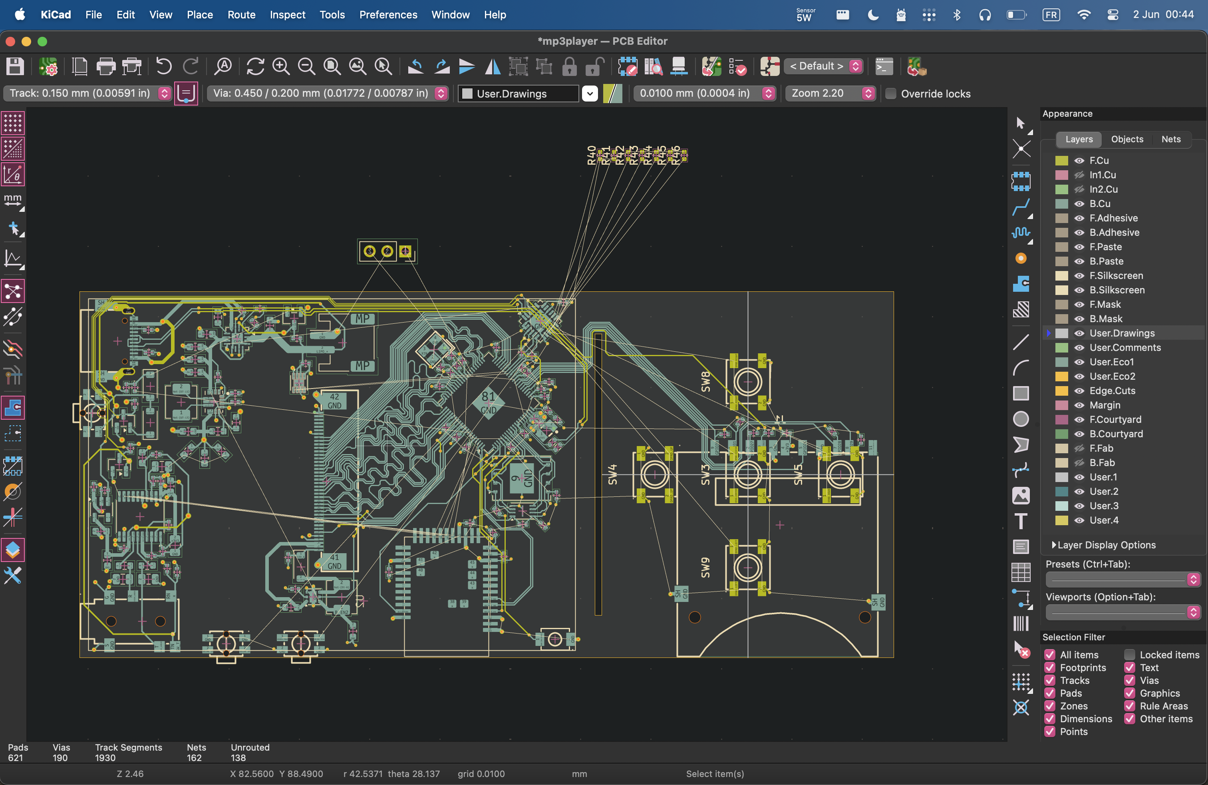
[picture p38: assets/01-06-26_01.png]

\
_routing..._
\
\
**Total time spent: 43 hours**

## 3nd June 2026

Routing is finished! It took a lot of time because i actually moved a lot of traces around to try to keep the planes cleaner, remove useless vias where I could & add the debug header. I'm quite proud of how it turned out!\
\
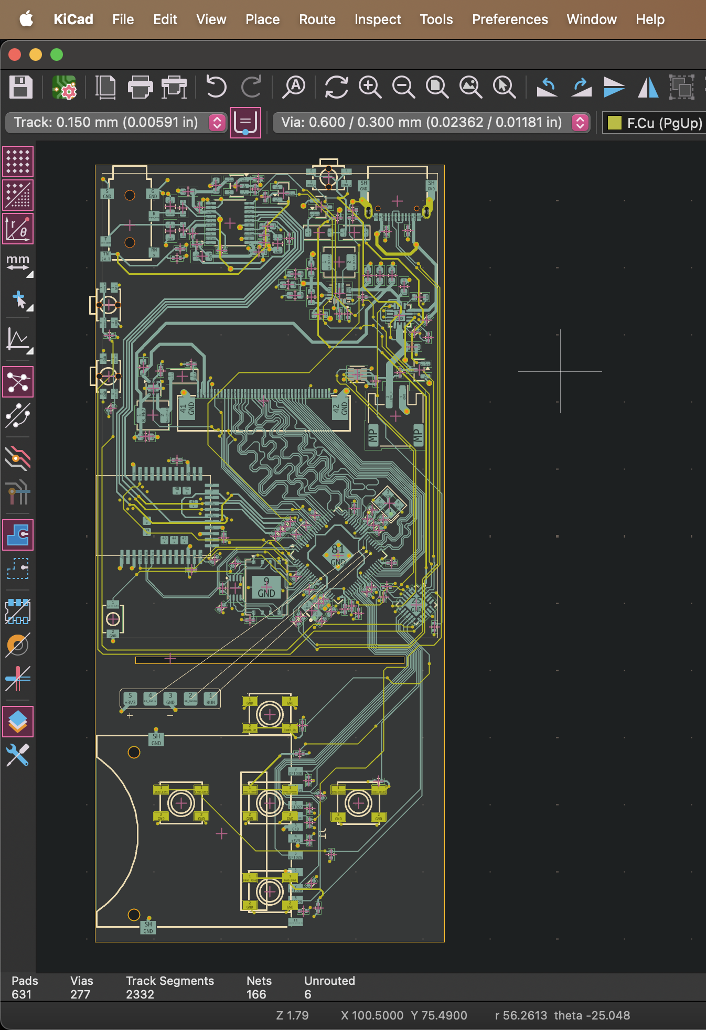
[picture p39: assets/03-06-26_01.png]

\
_final routing_
\
\
I also tried to get a quote at jlcpcb and uh i might be cooked.\
\
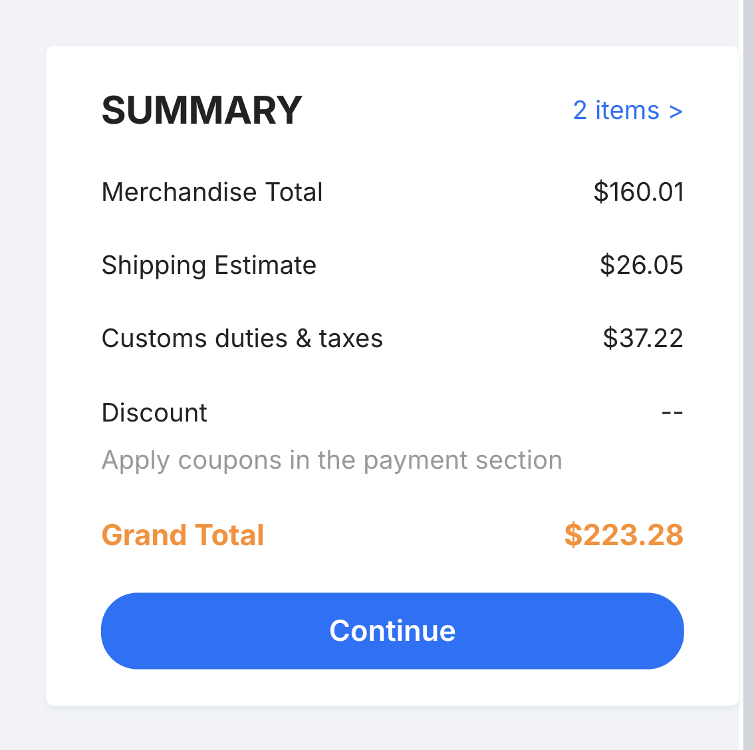
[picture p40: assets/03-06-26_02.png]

\
_jlcpcb quote..._
\
\
I'm thinking of maybe getting a hotplate + stencil & soldering it myself.\
That'd be pretty cool + would sove the 69$ of extended component fee... I just need to trust myself not to mess it up & find a cheap hotplate pf...\
Now time for the case & firmware!\
Oh also, jlcpcb wants to charge me 40$ more to get a white pcb :sob:. Since my whole vision for the design was based on a white pcb + transparent case, I might just go with that & pay but I'm not sure\
\
**Total time spent: 49 hours**

## 4th June 2026

Today I went on a polishing spree!

- rounded the corners of the pcb
- made the fpc slot a bit larger so the connector doesn't break
- fixed footprints where mounting holes were tht holes instead of npt
- removed duplicated vias
- removed broken traces
- broken footprint with way too much solder mask
- connecting something to gnd (oops i forgot)

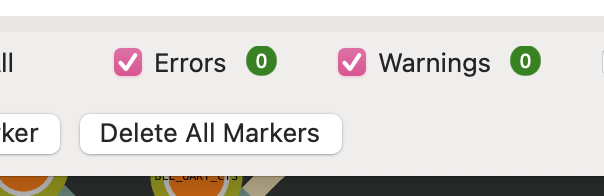
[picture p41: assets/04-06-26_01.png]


_0 errors omg_
\
\
Now I need to actually lockin on the case :sob:
**Total time spent: 51 hours**

## 12th June 2026

I'm back \o/\
Today I:

- added resistors on uart lines for the bluetooth module according to the datasheet
- redesigned the whole bluetooth module part to add antenna clearance because i forgot about it :sob:

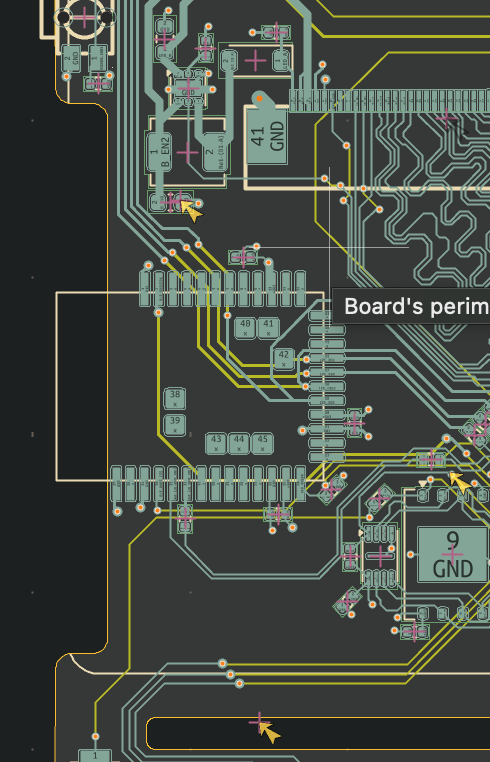
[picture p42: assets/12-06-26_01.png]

\
_redesign_

**Total time spent: 54 hours**

## 14th June 2026

Today I focused on making a case for it!\
I made a lot of research on how i could join parts & battled with onshape to get my pcb & other components in my file.\
I also decided to go with simple petg instead of resin because I need this quickly/cheaply and I don't have a resin printer.\
Battery form factor changed to 505050 because else it's going to be very thick :sob:\
\
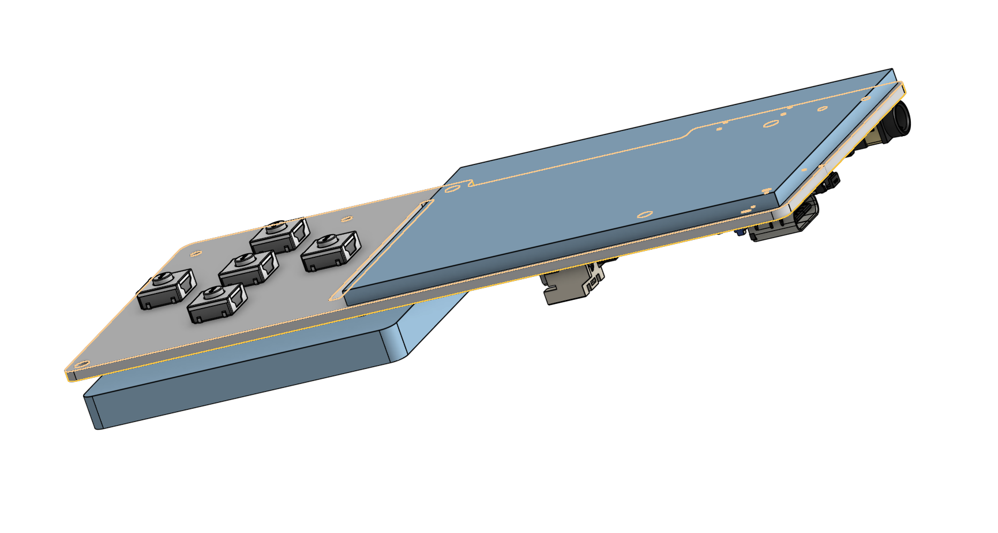
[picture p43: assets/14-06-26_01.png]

\
_new mounting holes_
\
\
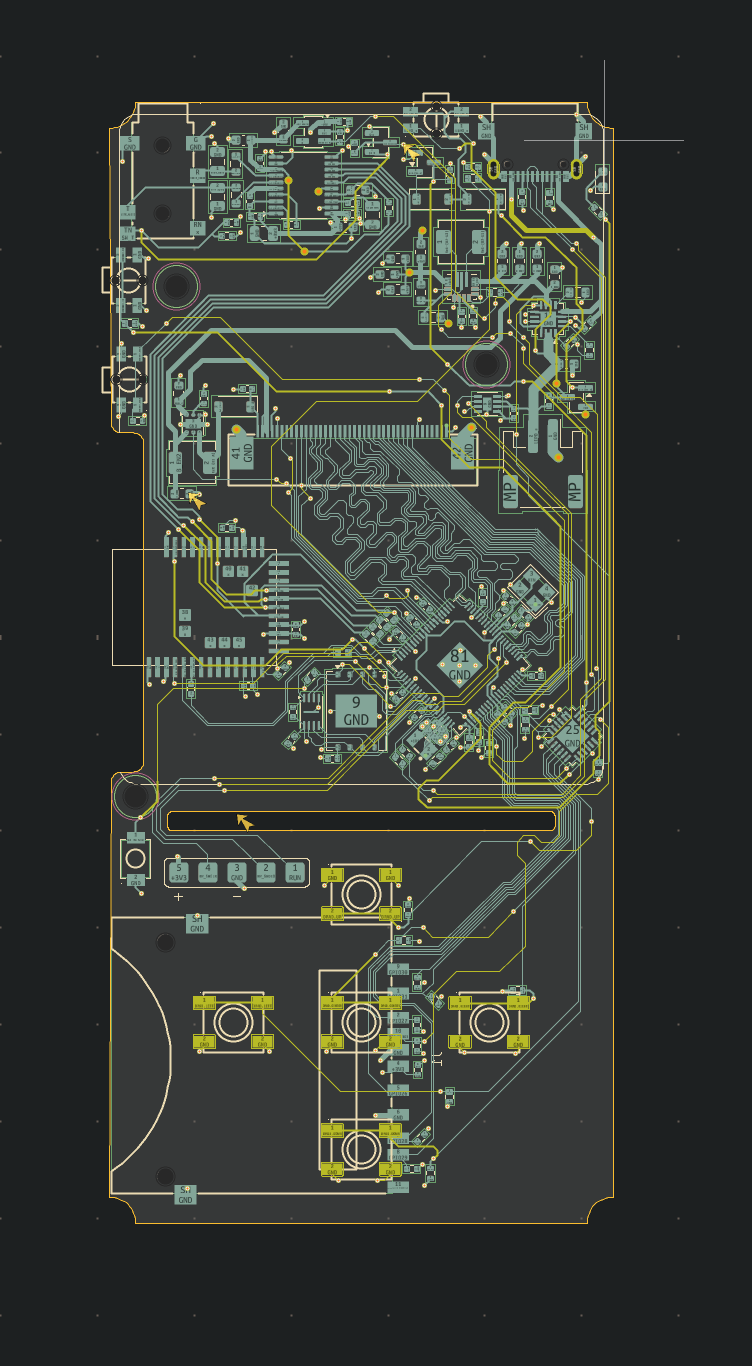
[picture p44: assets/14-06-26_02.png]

\
_onshaep thingies_
\
**Total time spent: 57 hours**

## 15th June 2026

Turns out sleeping a normal amount of time makes you more productive!\
Today I really locked in & finished the case design!\
It's not perfect yet, but I think I'm 90% done with it!\
I had to move stuff around on my pcb & reroute some traces to make it fit better in the case (dpad moved up, horizontal buttons moved sideways, ...).\
(my pcb left side wasn't straight for some reason??? :sob:)\
\
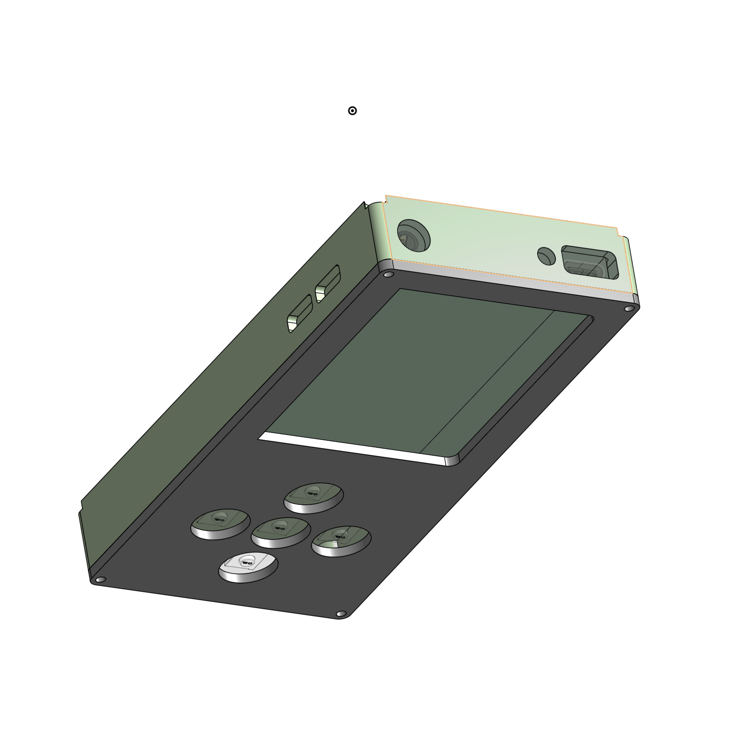
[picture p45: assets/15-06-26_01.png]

\
_case design_
\
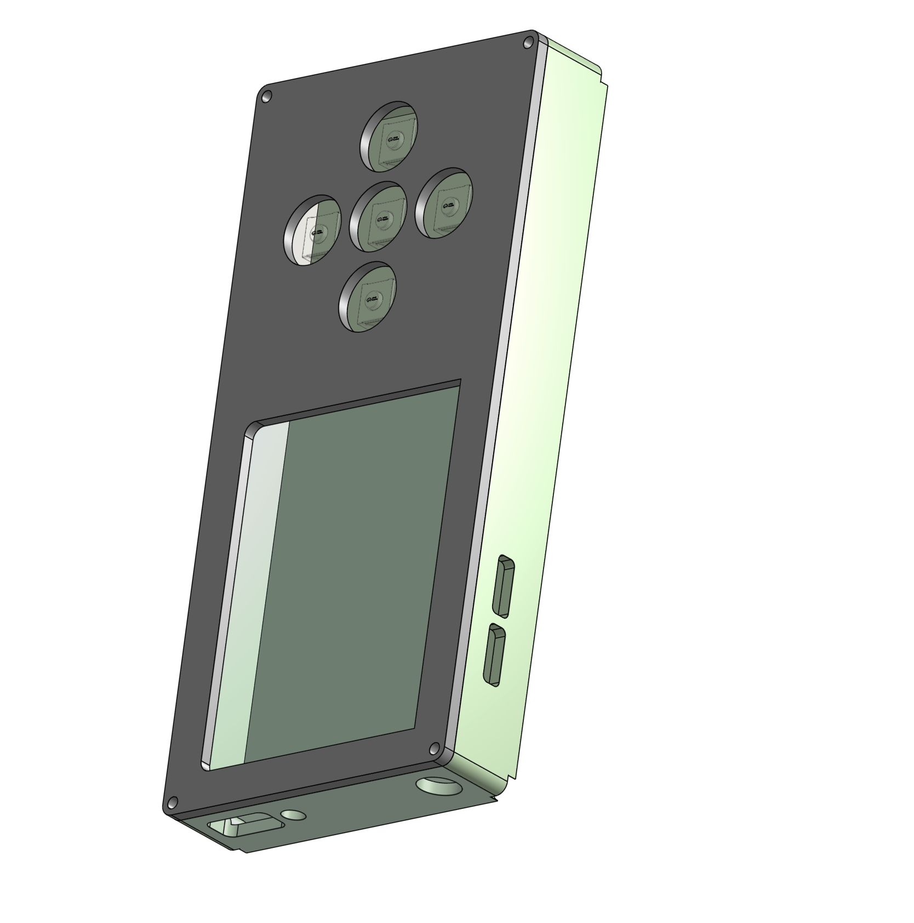
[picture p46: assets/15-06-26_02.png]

\
_case design_
\

\
_pcb update_
\
\
I'm very bad at CAD so this took forever, but I'm really happy with how it turned out!\
I'm thinking of printing different parts in different colors to make it look cooler :p. I could also bring different cases to opensauce & disassemble it to show the insides.

**Total time spent: 62 hours**

## 17th June 2026

This is going to be a long journal entry & a long commit cause I did a lot today & forgot to journal yesterday :pensive:\
I started the firmware!\
I first started by setting up the project structure & designing a hal so that I can run the ui on my computer to test it!\
\

\
_first time the ui ran on my computer!_
\
\
I then started working on the ui itself!\
Did some figma design with a friend but didn't really end up using it\
\

\
_ui design_
\
\
I then started implementing some basic ui system (text, images, buttons, widget system...)!\
\

\
_totally what I wanted to write trust_
\
\
After a lot of trial & error, I got something to work with the virtual sdcard!\
\


\
_basic music player!!!_
\
\
I also made a bunch of tooling for fonts, upload to the sdcard & running the emulator.\
No working music or settings or anything yet but this is definitely going somewhere!!!

**Total time spent: 70 hours**

## 18th June 2026

Today I continued my work on the firmware...\
Tbh i'm getting quite bored of that but we need to ship this thing :sob:\
\
Things I did today:

- way better fonts
- fixed padding/margin things
- new now playing screen
- status bar!
- better dpad navigation

I didn't really worked on the pico sdk implementation of the hal though... so that's what I need to focus on tomorrow.\
\

\
_new now playing screen_
\
\

\
_new library_

**Total time spent: 75 hours**

## 19th June 2026

New firmware features:

- charging & battery icon
- volume control
- settings screen
- bluetooth pairing & connecting screen + status bar integration
- mp3 decoding & playback actually working
- pico hal!

Screenshots!:\
\



**Total time spent: 81 hours**

## 20th June 2026

Today I finished the case (I forgot to make the buttons :sob:).\
I also made a few blender renders for the readme!\
\

\
_blender render_
\


\
_buttons!!_
\
\
I finished the day by writing a cool readme & finally shipping this project!

**Total time spent: 85 hours**

## 21st June 2026

Shipping day...\
I first started by trying to order the pcb with pcba on jlcpcb but they wanted 220$ :sob: (and even more for a white pcb aaaa)\
So I decided to not get pcba & solder it myself!\
I then tried to start an order on lcsc with my bom but realized that most of my passives were out of stock :(\
After a lot of time spent trying to find replacements, I ended up with a new bom & a way more reasonable price!\
\

\

\
\
And I can order white!!!

**Total time spent: 89 hours**

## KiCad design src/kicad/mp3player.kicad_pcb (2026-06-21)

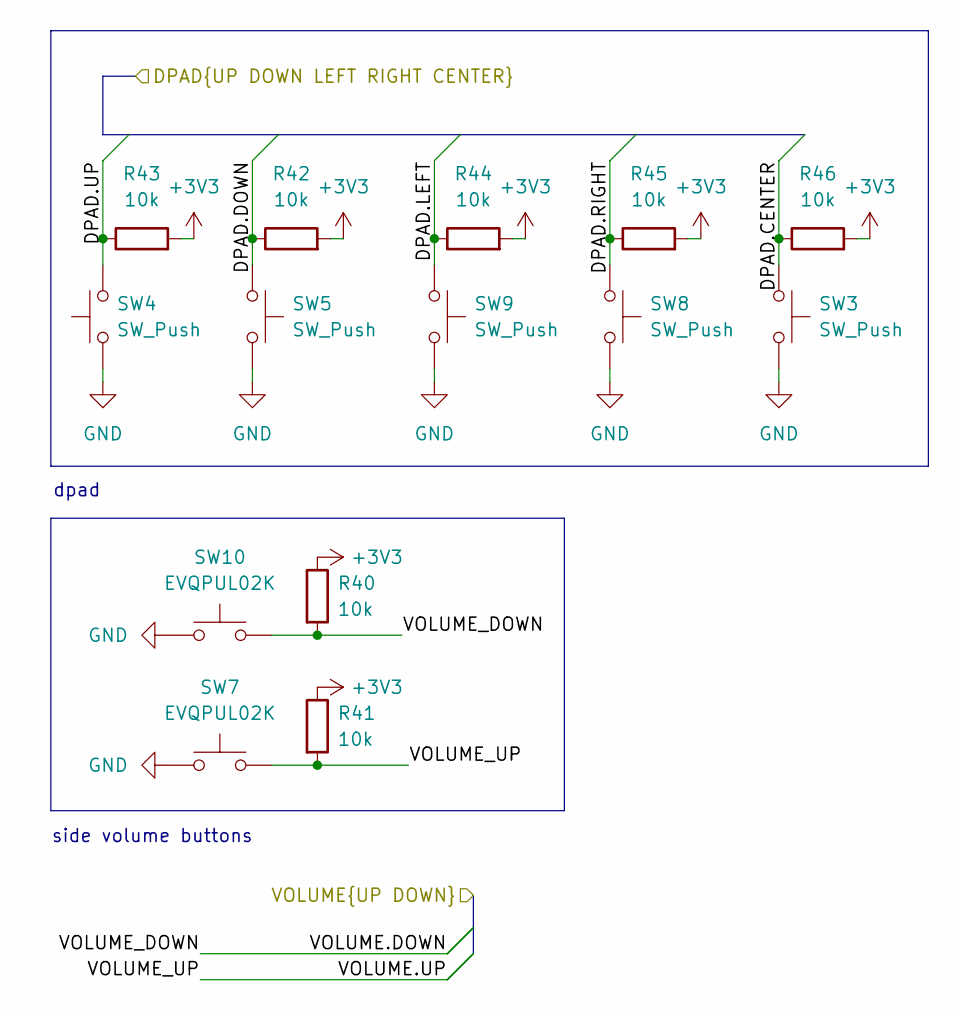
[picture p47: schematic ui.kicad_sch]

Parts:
R40, R41, R42, R43, R44, R45, R46: 10k; R_0402_1005Metric; LCSC Part C2906861
SW3, SW4, SW5, SW8, SW9: SW_Push; SW-SMD_4P-L6.2-W6.2-P4.00-LS6.8; LCSC Part C115354
SW7, SW10: EVQPUL02K; KEY-SMD_4P-L4.7-W3.5-P1.70-LS6.4-EH; LCSC Part C79175

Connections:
+3V3: R40.1, R41.1, R42.2, R43.2, R44.2, R45.2, R46.2; also elsewhere on the board
/processing/DPAD.CENTER: R46.1, SW3.1; also elsewhere on the board
/processing/DPAD.DOWN: R42.1, SW5.1; also elsewhere on the board
/processing/DPAD.LEFT: R44.1, SW9.1; also elsewhere on the board
/processing/DPAD.RIGHT: R45.1, SW8.1; also elsewhere on the board
/processing/DPAD.UP: R43.1, SW4.2; also elsewhere on the board
/processing/VOLUME.DOWN: R40.2, SW10.1; also elsewhere on the board
/processing/VOLUME.UP: R41.2, SW7.2; also elsewhere on the board
GND: SW3.2, SW4.1, SW5.2, SW7.1, SW8.2, SW9.2, SW10.2; also elsewhere on the board

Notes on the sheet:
dpad
side volume buttons

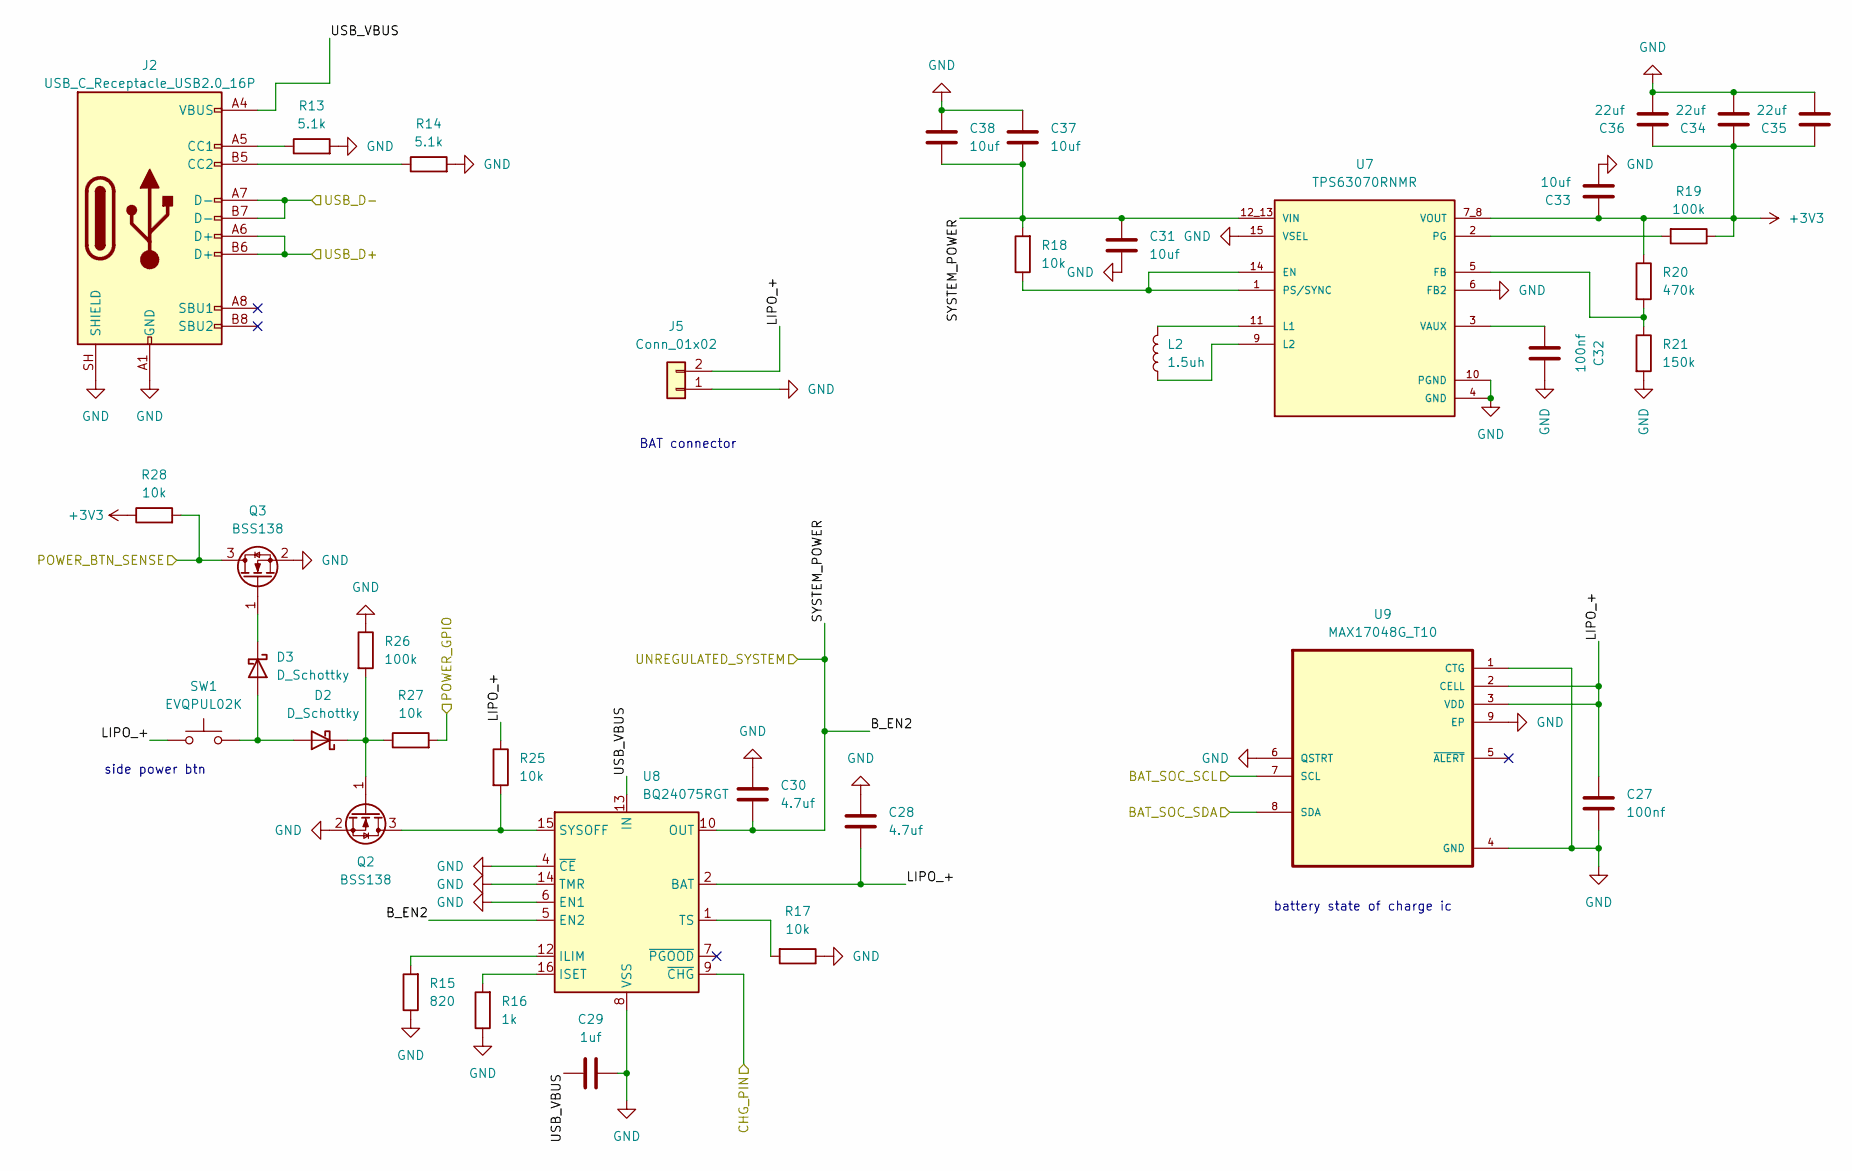
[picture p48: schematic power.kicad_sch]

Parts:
C27, C32: 100nf; C_0402_1005Metric; LCSC Part C1525
C28, C30: 4.7uf; C_0603_1608Metric; LCSC Part C19666
C29: 1uf; C_0402_1005Metric; LCSC Part C307427
C31, C33, C37, C38: 10uf; C_0603_1608Metric; LCSC Part C96446
C34, C35, C36: 22uf; C_0603_1608Metric; LCSC Part C59461
D2, D3: D_Schottky; D_SOD-123; LCSC Part C8598
J2: USB_C_Receptacle_USB2.0_16P; USB-C-SMD_GT-USB-7047C; LCSC Part C963218
J5: Conn_01x02; JST_PH_S2B-PH-SM4-TB_1x02-1MP_P2.00mm_Horizontal; LCSC Part C295747
L2: 1.5uh; L_Sunlord_MWSA0402S; LCSC Part C351088
Q2, Q3: BSS138; SOT-23; LCSC Part C52895
R13, R14: 5.1k; R_0402_1005Metric; LCSC Part C852856
R15: 820; R_0603_1608Metric; Tolerance 1%; LCSC Part C23253
R16: 1k; R_0402_1005Metric; Tolerance 1%; LCSC Part C852624
R17, R18, R25, R27, R28: 10k; R_0402_1005Metric; LCSC Part C2906861
R19, R26: 100k; R_0402_1005Metric; LCSC Part C481918
R20: 470k; R_0603_1608Metric; LCSC Part C2907040
R21: 150k; R_0603_1608Metric; LCSC Part C326734
SW1: EVQPUL02K; KEY-SMD_4P-L4.7-W3.5-P1.70-LS6.4-EH; LCSC Part C79175
U7: TPS63070RNMR; VREG_TPS63070RNMR; PARTREV B; LCSC Part C109322
U8: BQ24075RGT; VQFN-16-1EP_3x3mm_P0.5mm_EP1.6x1.6mm; LCSC Part C15464
U9: MAX17048G_T10; SON50P200X200X80-9N; LCSC Part C2682616

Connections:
+3V3: C33.1, C34.1, C35.1, C36.1, R19.1, R20.1, R28.1, U7.7_8 (VOUT); also elsewhere on the board
/power/B_EN2: C30.2, C31.1, C37.1, C38.2, R18.2, U7.12_13 (VIN), U8.5 (EN2), U8.10 (OUT), U8.11 (OUT); also elsewhere on the board
/power/CHG_PIN: U8.9 (~CHG); also elsewhere on the board
/power/LIPO_+: C27.1, C28.2, J5.2, R25.1, SW1.1, U8.2 (BAT), U8.3 (BAT), U9.2 (CELL), U9.3 (VDD)
/power/POWER_BTN_SENSE: Q3.3 (D), R28.2; also elsewhere on the board
/power/POWER_GPIO: R27.2; also elsewhere on the board
/power/USB_D+: J2.A6 (D+), J2.B6 (D+); also elsewhere on the board
/power/USB_D-: J2.A7 (D-), J2.B7 (D-); also elsewhere on the board
/power/USB_VBUS: C29.2, J2.A4 (VBUS), J2.A9 (VBUS), J2.B4 (VBUS), J2.B9 (VBUS), U8.13 (IN)
/processing/I2C_SCL: U9.7 (SCL); also elsewhere on the board
/processing/I2C_SDA: U9.8 (SDA); also elsewhere on the board
GND: C27.2, C28.1, C29.1, C30.1, C31.2, C32.2, C33.2, C34.2, C35.2, C36.2, C37.2, C38.1, J2.A1 (GND), J2.A12 (GND), J2.B1 (GND), J2.B12 (GND), J2.SH (SHIELD), J5.1, Q2.2 (S), Q3.2 (S), R13.2, R14.2, R15.1, R16.1, R17.1, R21.2, R26.1, U7.4 (GND), U7.6 (FB2), U7.10 (PGND), U7.15 (VSEL), U8.4 (~CE), U8.6 (EN1), U8.8 (VSS), U8.14 (TMR), U8.17 (VSS), U9.1 (CTG), U9.4 (GND), U9.6 (QSTRT), U9.9 (EP); also elsewhere on the board
unnamed: D2.2 (A), D3.2 (A), SW1.2
unnamed: D2.1 (K), Q2.1 (G), R26.2, R27.1
unnamed: D3.1 (K), Q3.1 (G)
unnamed: J2.A5 (CC1), R13.1
unnamed: J2.B5 (CC2), R14.1
unnamed: Q2.3 (D), R25.2, U8.15 (SYSOFF)
unnamed: R18.1, U7.1 (PS/SYNC), U7.14 (EN)
unnamed: R20.2, R21.1, U7.5 (FB)
unnamed: L2.2, U7.11 (L1)
unnamed: L2.1, U7.9 (L2)
unnamed: R19.2, U7.2 (PG)
unnamed: C32.1, U7.3 (VAUX)
unnamed: R15.2, U8.12 (ILIM)
unnamed: R16.2, U8.16 (ISET)
unnamed: R17.2, U8.1 (TS)

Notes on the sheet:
battery state of charge ic
BAT connector
side power btn

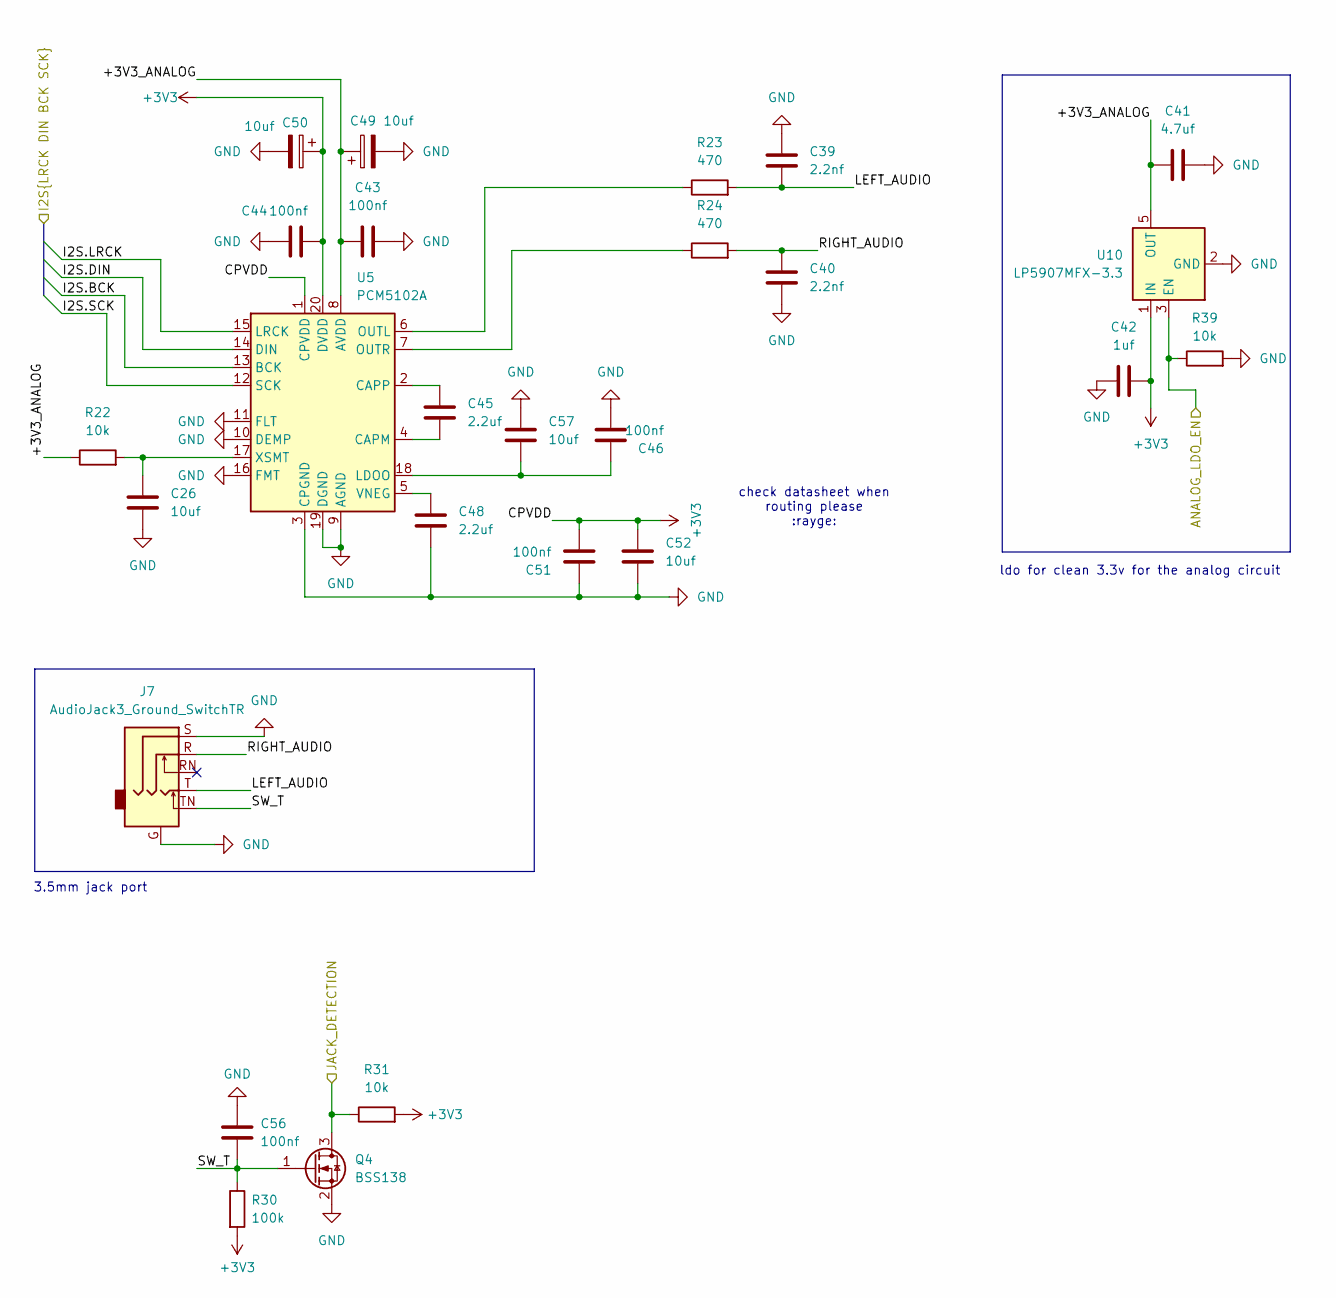
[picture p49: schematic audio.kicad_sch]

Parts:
C26, C49, C50: 10uf; C_0603_1608Metric; LCSC Part C96446
C39, C40: 2.2nf; C_0805_2012Metric; LCSC Part C28260
C41: 4.7uf; C_0603_1608Metric; LCSC Part C19666
C42: 1uf; C_0402_1005Metric; LCSC Part C307427
C43, C44, C46, C51, C56: 100nf; C_0402_1005Metric; LCSC Part C1525
C45, C48: 2.2uf; C_0402_1005Metric; LCSC Part C12530
C52, C57: 10uf; C_0805_2012Metric; LCSC Part C1713
J7: AudioJack3_Ground_SwitchTR; AUDIO-SMD_PJ-342-141; LCSC Part C7507452
Q4: BSS138; SOT-23; LCSC Part C52895
R22, R31, R39: 10k; R_0402_1005Metric; LCSC Part C2906861
R23, R24: 470; R_0603_1608Metric; Tolerance 1%; LCSC Part C218042
R30: 100k; R_0402_1005Metric; LCSC Part C481918
U5: PCM5102A; TSSOP-20_4.4x6.5mm_P0.65mm; LCSC Part C107671
U10: LP5907MFX-3.3; SOT-23-5; LCSC Part C23380874

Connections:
+3V3: C42.1, C44.1, C50.1, C51.1, C52.2, R30.2, R31.2, U5.1 (CPVDD), U5.20 (DVDD), U10.1 (IN); also elsewhere on the board
/audio/+3V3_ANALOG: C41.1, C43.1, C49.1, R22.1, U5.8 (AVDD), U10.5 (OUT)
/audio/ANALOG_LDO_EN: R39.1, U10.3 (EN); also elsewhere on the board
/audio/I2S.BCK: U5.13 (BCK); also elsewhere on the board
/audio/I2S.DIN: U5.14 (DIN); also elsewhere on the board
/audio/I2S.LRCK: U5.15 (LRCK); also elsewhere on the board
/audio/I2S.SCK: U5.12 (SCK); also elsewhere on the board
/audio/JACK_DETECTION: Q4.3 (D), R31.1; also elsewhere on the board
/audio/LEFT_AUDIO: C39.2, J7.T, R23.2
/audio/RIGHT_AUDIO: C40.1, J7.R, R24.2
/audio/SW_T: C56.2, J7.TN, Q4.1 (G), R30.1
GND: C26.2, C39.1, C40.2, C41.2, C42.2, C43.2, C44.2, C46.1, C48.1, C49.2, C50.2, C51.2, C52.1, C56.1, C57.2, J7.G, J7.S, Q4.2 (S), R39.2, U5.3 (CPGND), U5.9 (AGND), U5.10 (DEMP), U5.11 (FLT), U5.16 (FMT), U5.19 (DGND), U10.2 (GND); also elsewhere on the board
unnamed: C45.1, U5.4 (CAPM)
unnamed: C45.2, U5.2 (CAPP)
unnamed: C46.2, C57.1, U5.18 (LDOO)
unnamed: R23.1, U5.6 (OUTL)
unnamed: R24.1, U5.7 (OUTR)
unnamed: C48.2, U5.5 (VNEG)
unnamed: C26.1, R22.2, U5.17 (XSMT)

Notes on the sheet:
ldo for clean 3.3v for the analog circuit
3.5mm jack port
check datasheet when routing please :rayge:

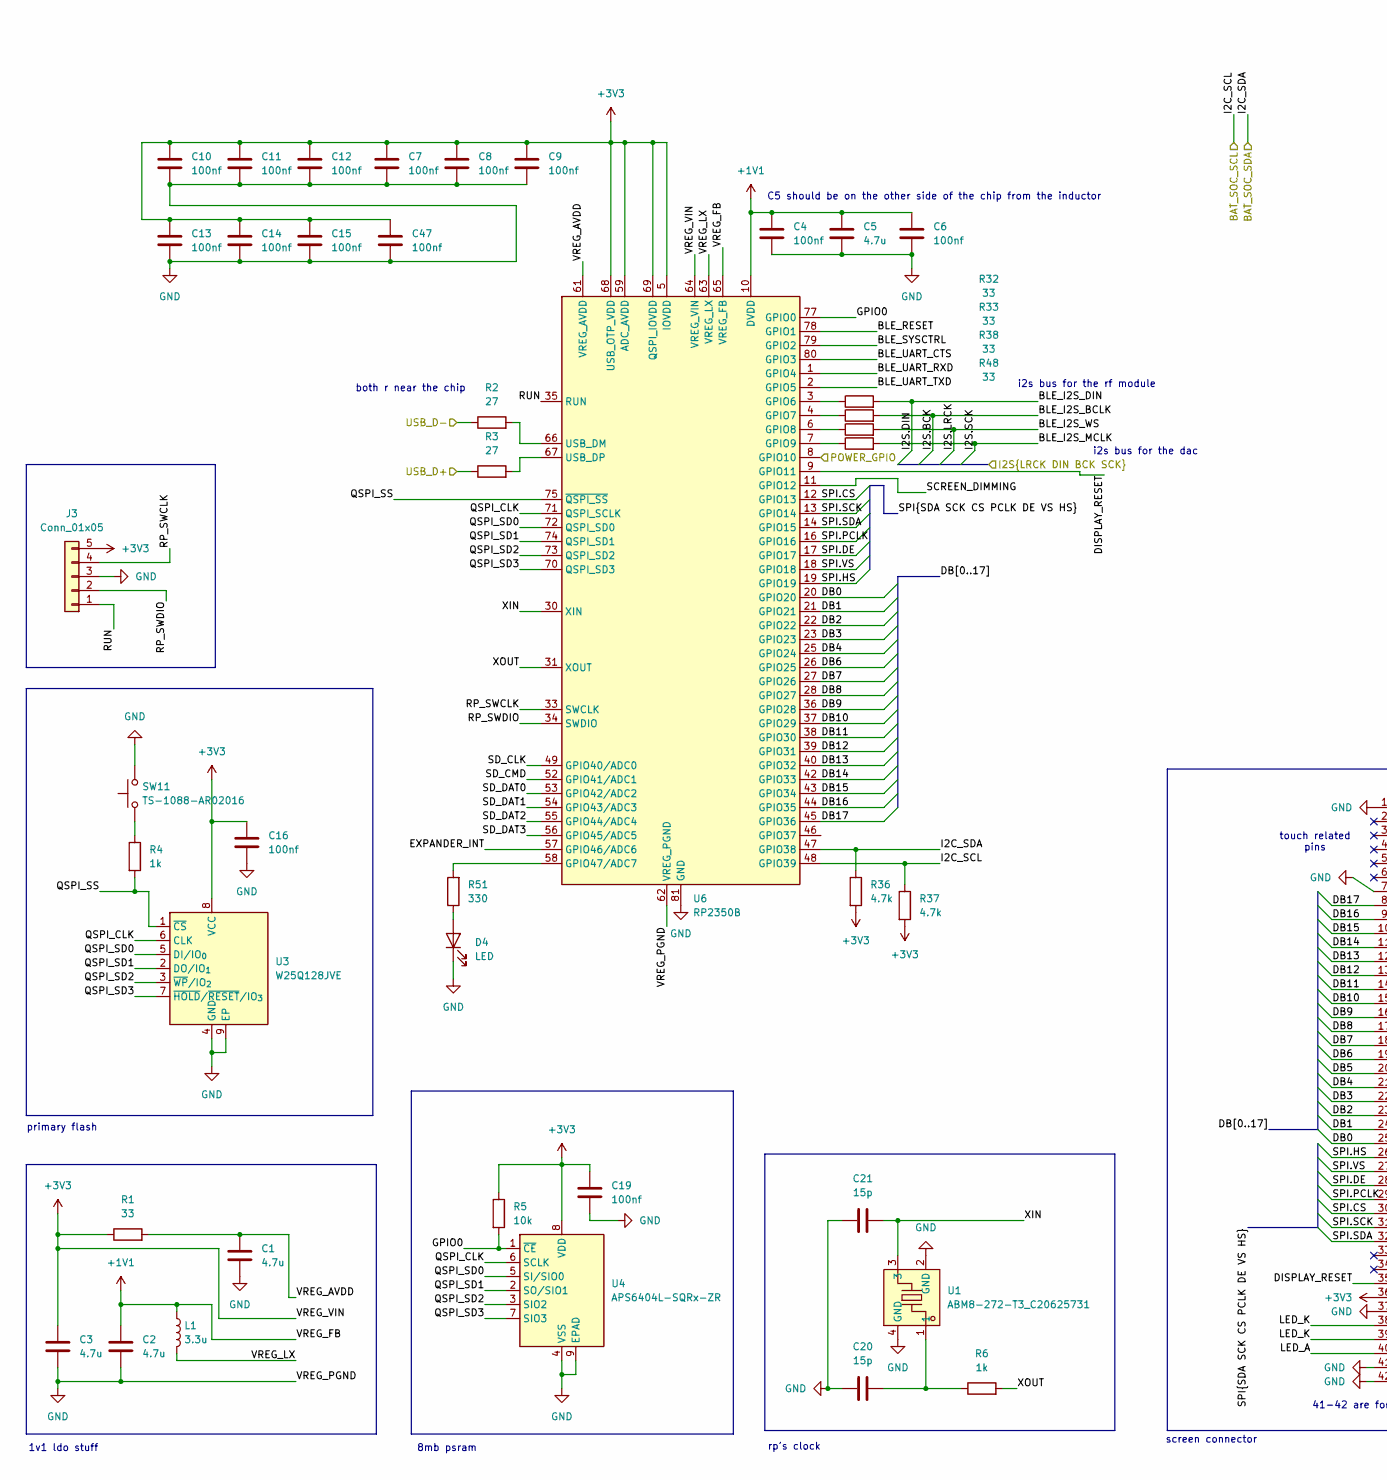
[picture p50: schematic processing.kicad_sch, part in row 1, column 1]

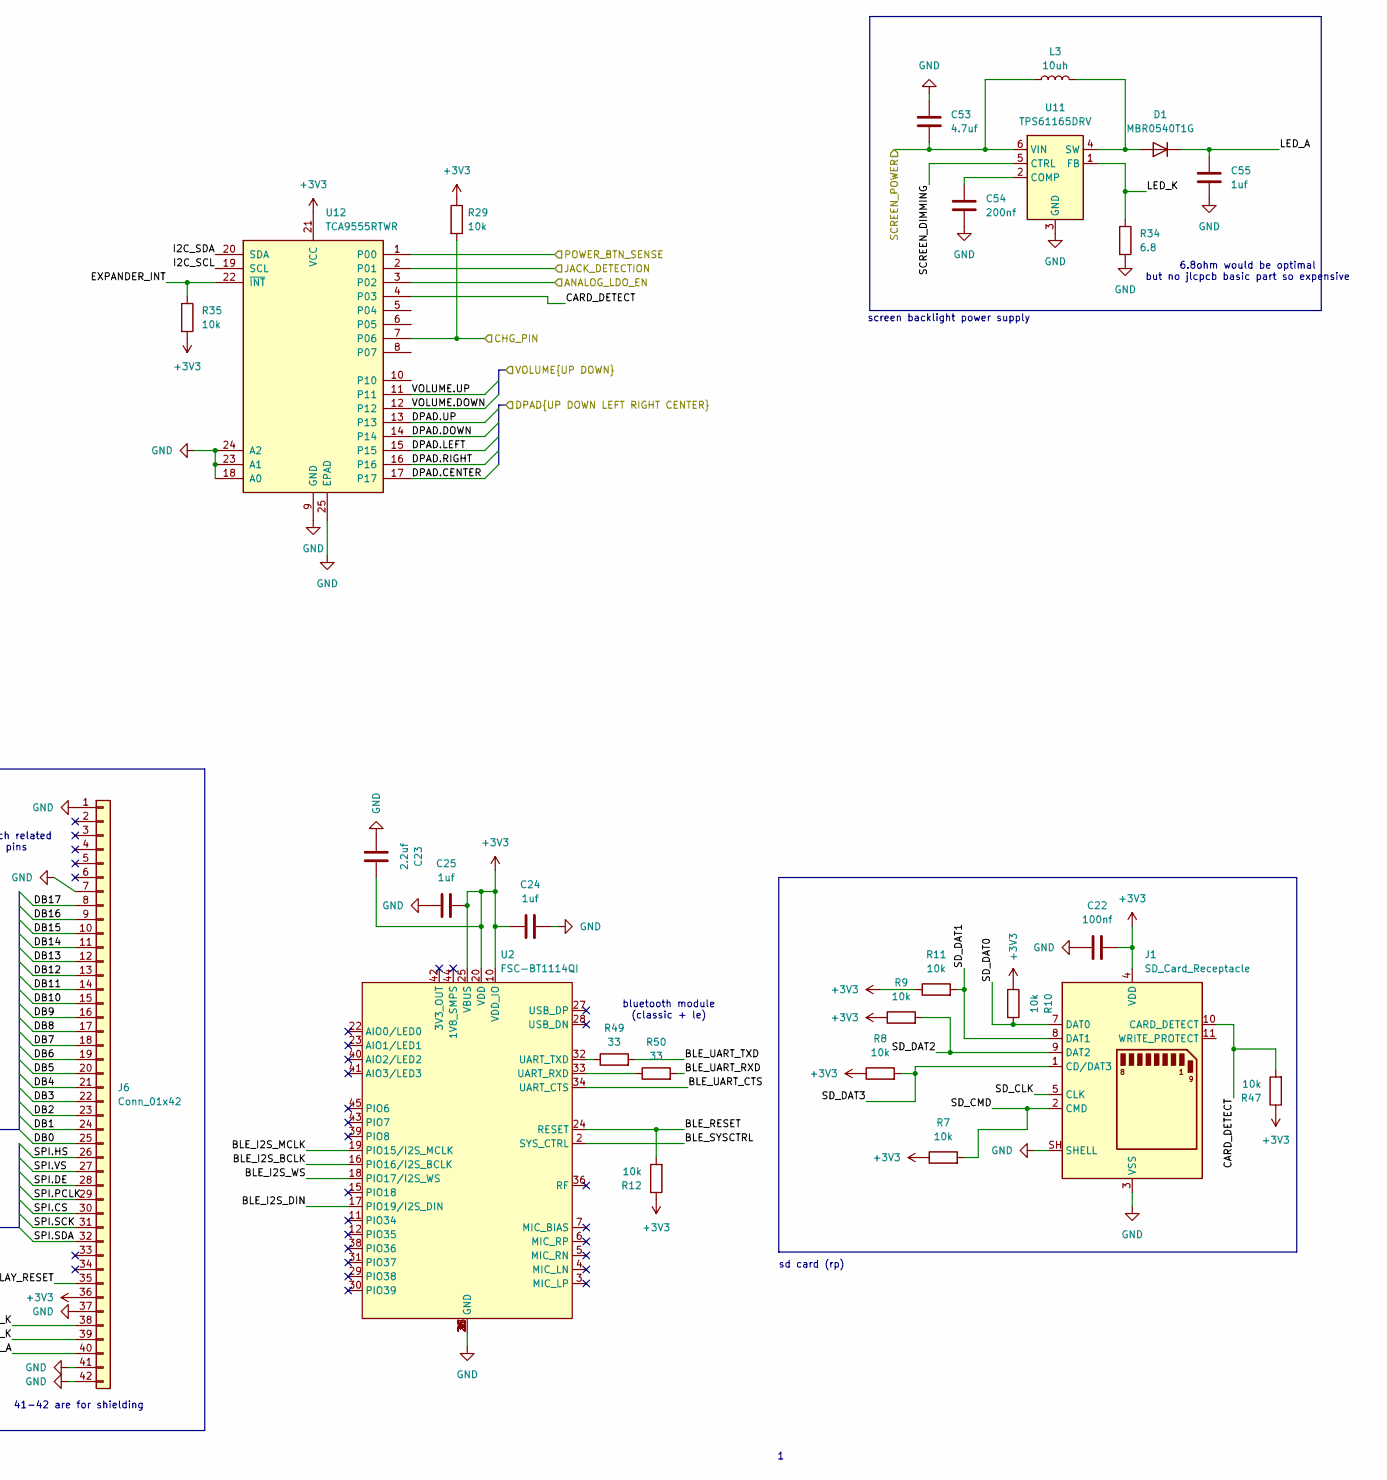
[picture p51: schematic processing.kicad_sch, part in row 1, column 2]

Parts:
C1, C3, C5: 4.7u; C_0402_1005Metric; LCSC Part C23733
C2: 4.7u; C_0402_1005Metric; LCSC Part C368809
C4, C6, C7, C8, C9, C10, C11, C12, C13, C14, C15, C16, C19, C22, C47: 100nf; C_0402_1005Metric; LCSC Part C1525
C20, C21: 15p; C_0402_1005Metric; LCSC Part C1548
C23: 2.2uf; C_0402_1005Metric; LCSC Part C12530
C24, C25, C55: 1uf; C_0402_1005Metric; LCSC Part C307427
C53: 4.7uf; C_0603_1608Metric; LCSC Part C19666
C54: 200nf; C_0402_1005Metric; LCSC Part C16772
D1: MBR0540T1G; D_SOD-123; LCSC Part C21353
D4: LED; LED_0603_1608Metric; LCSC Part C2286
J1: SD_Card_Receptacle; SD-SMD_SD-006M; LCSC Part C125615
J3: Conn_01x05; test_pads; LCSC Part //
J6: Conn_01x42; FPC-SMD_AFC07-S40FCC00; LCSC Part C11062
L1: 3.3u; IND-SMD_L2.0-W1.6_AOTA-B201610S3R3-101-T; LCSC Part C42411119
L3: 10uh; L_TechFuse_SL0420; LCSC Part C22463809
R1, R32, R33, R38, R48, R49, R50: 33; R_0402_1005Metric; LCSC Part C2906931
R2, R3: 27; R_0402_1005Metric; LCSC Part C25105
R4, R6: 1k; R_0402_1005Metric; LCSC Part C852624
R5, R7, R8, R9, R10, R11, R12, R29, R35, R47: 10k; R_0402_1005Metric; LCSC Part C2906861
R34: 6.8; R_0603_1608Metric; Tolerance 1%; LCSC Part C2907056
R36, R37: 4.7k; R_0402_1005Metric; LCSC Part C2906941
R51: 330; R_0402_1005Metric; LCSC Part C71626
SW11: TS-1088-AR02016; SW-SMD_L3.9-W3.0-P4.45; LCSC Part C720477
U1: ABM8-272-T3_C20625731; CRYSTAL-SMD_4P-L3.2-W2.5-BL; MPN ABM8-272-T3; LCSC Part C20625731
U2: FSC-BT1114QI; LCSC Part //
U3: W25Q128JVE; WSON-8-1EP_8x6mm_P1.27mm_EP3.4x4.3mm; LCSC Part C2456297
U4: APS6404L-SQRx-ZR; Winbond_USON-8-1EP_3x2mm_P0.5mm_EP0.2x1.6mm; LCSC Part C3040877
U6: RP2350B; QFN-80-1EP_10x10mm_P0.4mm_EP3.4x3.4mm; LCSC Part C42415655
U11: TPS61165DRV; WSON-6-1EP_2x2mm_P0.65mm_EP1x1.6mm; LCSC Part C122568
U12: TCA9555RTWR; WQFN-24-1EP_4x4mm_P0.5mm_EP2.45x2.45mm; LCSC Part C140277

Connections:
+1V1: C2.1, C4.1, C5.1, C6.1, L1.1, U6.10 (DVDD), U6.32 (DVDD), U6.51 (DVDD), U6.65 (VREG_FB)
+3V3: C3.1, C7.1, C8.1, C9.1, C10.1, C11.1, C12.1, C13.1, C14.1, C15.1, C16.1, C19.2, C22.2, C23.2, C24.1, C25.1, C47.1, J1.4 (VDD), J3.5, J6.36, R1.1, R5.1, R7.1, R8.1, R9.1, R10.1, R11.1, R12.1, R29.1, R35.2, R36.2, R37.2, R47.1, U2.10 (VDD_IO), U2.20 (VDD), U2.25 (VBUS), U3.8 (VCC), U4.8 (VDD), U6.5 (IOVDD), U6.15 (IOVDD), U6.24 (IOVDD), U6.29 (IOVDD), U6.41 (IOVDD), U6.50 (IOVDD), U6.59 (ADC_AVDD), U6.60 (IOVDD), U6.64 (VREG_VIN), U6.68 (USB_OTP_VDD), U6.69 (QSPI_IOVDD), U6.76 (IOVDD), U12.21 (VCC); also elsewhere on the board
/audio/ANALOG_LDO_EN: U12.3 (P02); also elsewhere on the board
/audio/I2S.BCK: R33.2, U2.16 (PIO16/I2S_BCLK); also elsewhere on the board
/audio/I2S.DIN: R32.2, U2.17 (PIO19/I2S_DIN); also elsewhere on the board
/audio/I2S.LRCK: R38.2, U2.18 (PIO17/I2S_WS); also elsewhere on the board
/audio/I2S.SCK: R48.2, U2.19 (PIO15/I2S_MCLK); also elsewhere on the board
/audio/JACK_DETECTION: U12.2 (P01); also elsewhere on the board
/power/B_EN2: C53.2, L3.1, U11.6 (VIN); also elsewhere on the board
/power/CHG_PIN: R29.2, U12.7 (P06); also elsewhere on the board
/power/POWER_BTN_SENSE: U12.1 (P00); also elsewhere on the board
/power/POWER_GPIO: U6.8 (GPIO10); also elsewhere on the board
/power/USB_D+: R3.1; also elsewhere on the board
/power/USB_D-: R2.1; also elsewhere on the board
/processing/BLE_RESET: R12.2, U2.24 (RESET), U6.78 (GPIO1)
/processing/BLE_SYSCTRL: U2.2 (SYS_CTRL), U6.79 (GPIO2)
/processing/BLE_UART_CTS: U2.34 (UART_CTS), U6.80 (GPIO3)
/processing/BLE_UART_RXD: R50.2, U6.1 (GPIO4)
/processing/BLE_UART_TXD: R49.2, U6.2 (GPIO5)
/processing/CARD_DETECT: J1.10 (CARD_DETECT), R47.2, U12.4 (P03)
/processing/DB0: J6.25, U6.20 (GPIO20)
/processing/DB1: J6.24, U6.21 (GPIO21)
/processing/DB2: J6.23, U6.22 (GPIO22)
/processing/DB3: J6.22, U6.23 (GPIO23)
/processing/DB4: J6.21, U6.25 (GPIO24)
/processing/DB5: J6.20
/processing/DB6: J6.19, U6.26 (GPIO25)
/processing/DB7: J6.18, U6.27 (GPIO26)
/processing/DB8: J6.17, U6.28 (GPIO27)
/processing/DB9: J6.16, U6.36 (GPIO28)
/processing/DB10: J6.15, U6.37 (GPIO29)
/processing/DB11: J6.14, U6.38 (GPIO30)
/processing/DB12: J6.13, U6.39 (GPIO31)
/processing/DB13: J6.12, U6.40 (GPIO32)
/processing/DB14: J6.11, U6.42 (GPIO33)
/processing/DB15: J6.10, U6.43 (GPIO34)
/processing/DB16: J6.9, U6.44 (GPIO35)
/processing/DB17: J6.8, U6.45 (GPIO36)
/processing/DISPLAY_RESET: J6.35, U6.9 (GPIO11)
/processing/DPAD.CENTER: U12.17; also elsewhere on the board
/processing/DPAD.DOWN: U12.14; also elsewhere on the board
/processing/DPAD.LEFT: U12.15; also elsewhere on the board
/processing/DPAD.RIGHT: U12.16; also elsewhere on the board
/processing/DPAD.UP: U12.13; also elsewhere on the board
/processing/EXPANDER_INT: R35.1, U6.57 (GPIO46/ADC6), U12.22 (~INT)
/processing/GPIO0: R5.2, U4.1 (~CE), U6.77 (GPIO0)
/processing/I2C_SCL: R37.1, U6.48 (GPIO39), U12.19 (SCL); also elsewhere on the board
/processing/I2C_SDA: R36.1, U6.47 (GPIO38), U12.20 (SDA); also elsewhere on the board
/processing/LED_A: C55.2, D1.1 (K), J6.40
/processing/LED_K: J6.38, J6.39, R34.1, U11.1 (FB)
/processing/QSPI_CLK: U3.6 (CLK), U4.6 (SCLK), U6.71 (QSPI_SCLK)
/processing/QSPI_SD0: U3.5 (DI/IO_{0}), U4.5 (SI/SIO0), U6.72 (QSPI_SD0)
/processing/QSPI_SD1: U3.2 (DO/IO_{1}), U4.2 (SO/SIO1), U6.74 (QSPI_SD1)
/processing/QSPI_SD2: U3.3 (~WP/IO_{2}), U4.3 (SIO2), U6.73 (QSPI_SD2)
/processing/QSPI_SD3: U3.7 (~HOLD/~RESET/IO_{3}), U4.7 (SIO3), U6.70 (QSPI_SD3)
/processing/QSPI_SS: R4.2, U3.1 (~CS), U6.75 (~QSPI_SS)
/processing/RP_SWCLK: J3.4, U6.33 (SWCLK)
/processing/RP_SWDIO: J3.2, U6.34 (SWDIO)
/processing/RUN: J3.1, U6.35 (RUN)
/processing/SCREEN_DIMMING: U6.11 (GPIO12), U11.5 (CTRL)
/processing/SD_CLK: J1.5 (CLK), U6.49 (GPIO40/ADC0)
/processing/SD_CMD: J1.2 (CMD), R7.2, U6.52 (GPIO41/ADC1)
/processing/SD_DAT0: J1.7 (DAT0), R10.2, U6.53 (GPIO42/ADC2)
/processing/SD_DAT1: J1.8 (DAT1), R11.2, U6.54 (GPIO43/ADC3)
/processing/SD_DAT2: J1.9 (DAT2), R9.2, U6.55 (GPIO44/ADC4)
/processing/SD_DAT3: J1.1 (CD/DAT3), R8.2, U6.56 (GPIO45/ADC5)
/processing/SPI.CS: J6.30, U6.12 (GPIO13)
/processing/SPI.DE: J6.28, U6.17 (GPIO17)
/processing/SPI.HS: J6.26, U6.19 (GPIO19)
/processing/SPI.PCLK: J6.29, U6.16 (GPIO16)
/processing/SPI.SCK: J6.31, U6.13 (GPIO14)
/processing/SPI.SDA: J6.32, U6.14 (GPIO15)
/processing/SPI.VS: J6.27, U6.18 (GPIO18)
/processing/VOLUME.DOWN: U12.12; also elsewhere on the board
/processing/VOLUME.UP: U12.11; also elsewhere on the board
/processing/VREG_AVDD: C1.1, R1.2, U6.61 (VREG_AVDD)
/processing/VREG_LX: L1.2, U6.63 (VREG_LX)
/processing/XIN: C21.2, U1.3, U6.30 (XIN)
/processing/XOUT: R6.2, U6.31 (XOUT)
GND: C1.2, C2.2, C3.2, C4.2, C5.2, C6.2, C7.2, C8.2, C9.2, C10.2, C11.2, C12.2, C13.2, C14.2, C15.2, C16.2, C19.1, C20.1, C21.1, C22.1, C23.1, C24.2, C25.2, C47.2, C53.1, C54.2, C55.1, D4.1 (K), J1.3 (VSS), J1.6 (VSS), J1.SH (SHELL), J3.3, J6.1, J6.7, J6.37, J6.41, J6.42, R34.2, SW11.2, U1.2 (GND), U1.4 (GND), U2.1 (GND), U2.21 (GND), U2.26 (GND), U2.35 (GND), U2.37 (GND), U3.4 (GND), U3.9 (EP), U4.4 (VSS), U4.9 (EPAD), U6.62 (VREG_PGND), U6.81 (GND), U11.3 (GND), U11.7 (GND), U12.9 (GND), U12.18 (A0), U12.23 (A1), U12.24 (A2), U12.25 (EPAD); also elsewhere on the board
unnamed: C20.2, R6.1, U1.1
unnamed: D1.2 (A), L3.2, U11.4 (SW)
unnamed: D4.2 (A), R51.1
unnamed: R4.1, SW11.1
unnamed: R50.1, U2.33 (UART_RXD)
unnamed: R49.1, U2.32 (UART_TXD)
unnamed: R32.1, U6.3 (GPIO6)
unnamed: R33.1, U6.4 (GPIO7)
unnamed: R38.1, U6.6 (GPIO8)
unnamed: R48.1, U6.7 (GPIO9)
unnamed: R51.2, U6.58 (GPIO47/ADC7)
unnamed: R2.2, U6.66 (USB_DM)
unnamed: R3.2, U6.67 (USB_DP)
unnamed: C54.1, U11.2 (COMP)

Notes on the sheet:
bluetooth module (classic + le)
41-42 are for shielding
primary flash
rp's clock
8mb psram
C5 should be on the other side of the chip from the inductor
screen connector
both r near the chip
sd card (rp)
i2s bus for the rf module
6.8ohm would be optimal but no jlcpcb basic part so expensive
1v1 ldo stuff
i2s bus for the dac
screen backlight power supply
touch related pins

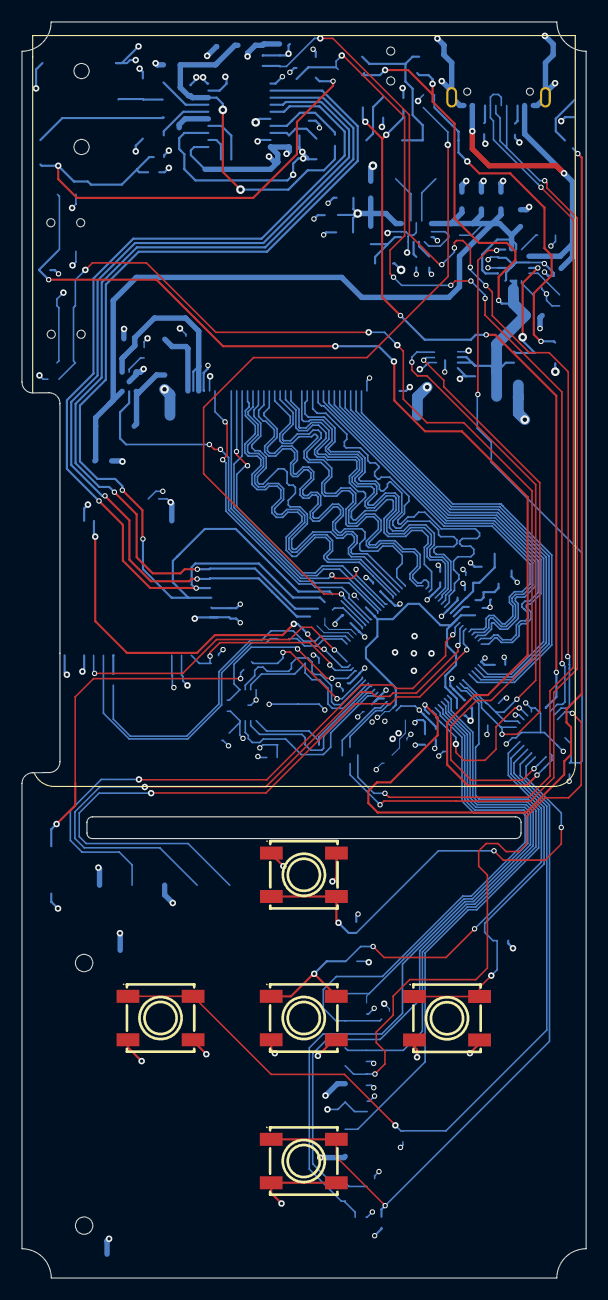
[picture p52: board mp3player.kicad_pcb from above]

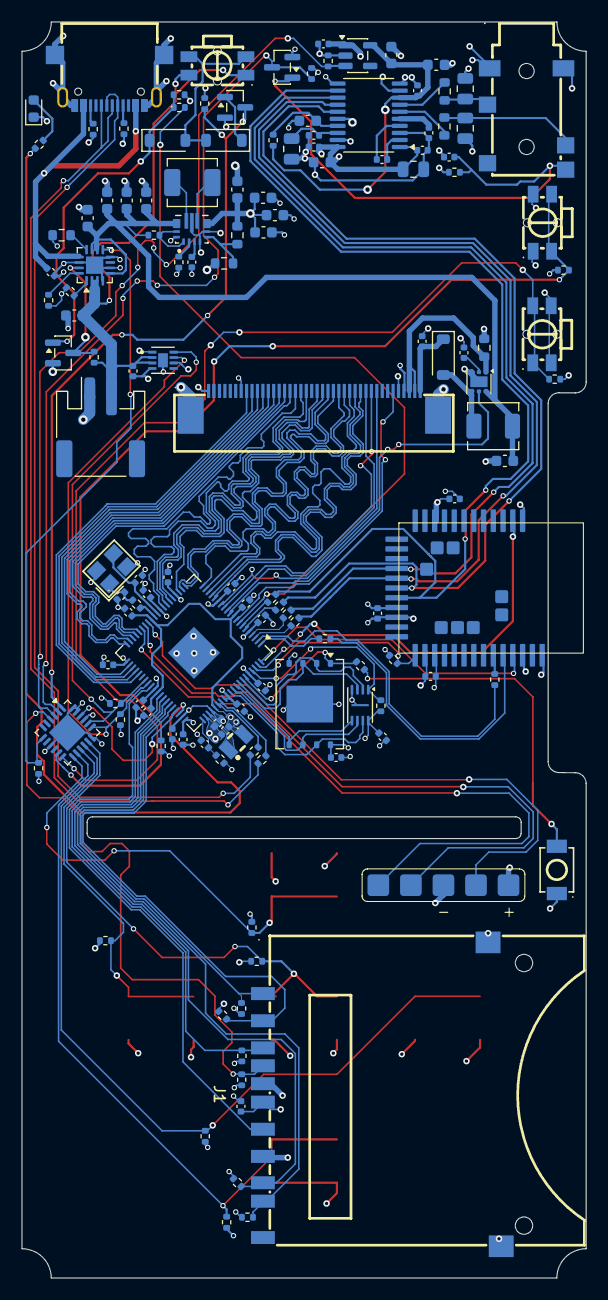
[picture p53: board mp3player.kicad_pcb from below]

Board: 4 copper layers, 52.0 x 115.7 mm, 143 parts (138 on the bottom side), 121 nets.

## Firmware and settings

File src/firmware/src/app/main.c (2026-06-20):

#include "../ui/components/statusbar.h"
#include "../ui/screen.h"
#include "../ui/screens/library.h"
#include "gfx.h"
#include "hal.h"
#include "hal_bluetooth.h"
#include "player.h"
#include "theme.h"

int main() {
  hal_display_init();
  hal_audio_init(44100);
  hal_bt_init();
  hal_input_init();
  hal_battery_init();

  theme_init();                         // built-in default theme
  theme_load_settings("/settings.ini"); // optional user theme override
  library_init();                       // scan scan

  screen_manager_t sm;
  sm_init(&sm);
  sm_push(&sm, library_screen_create(&sm));

  hal_input_t input;
  uint32_t last_time = hal_get_time_ms();
  int32_t time_accumulator = 0;
  const int32_t MS_PER_FRAME = 16;

  uint32_t last_battery_poll = 0;
  const uint32_t BATTERY_POLL_MS = 2000;

  while (true) {
    uint32_t current_time = hal_get_time_ms();
    int32_t elapsed = current_time - last_time;
    last_time = current_time;
    if (elapsed > 100)
      elapsed = 100;
    time_accumulator += elapsed;

    hal_bt_tick();

    if (current_time - last_battery_poll >= BATTERY_POLL_MS) {
      last_battery_poll = current_time;
      hal_battery_t battery;
      hal_battery_read(&battery);
      if (battery.present)
        status_bar_set_battery(battery.percent, battery.charging);
    }

    while (time_accumulator >= MS_PER_FRAME) {
      hal_input_read(&input);
      if (input.volume_up_pressed)
        player_volume_up();
      if (input.volume_down_pressed)
        player_volume_down();
      player_pump(); // decode + feed audio before screens read player state
      sm_update(&sm, &input, MS_PER_FRAME);
      time_accumulator -= MS_PER_FRAME;
    }

    gfx_clear_screen(g_theme->bg);
    sm_render(&sm);
    hal_display_present();

    uint32_t loop_end = hal_get_time_ms();
    if ((loop_end - current_time) < MS_PER_FRAME)
      hal_delay_ms(1);
  }

  return 0;
}

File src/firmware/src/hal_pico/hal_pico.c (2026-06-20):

#include "../app/hal.h"
#include "dpi.h"
#include "ff.h"
#include "hardware/i2c.h"
#include "pico/audio_i2s.h"
#include "pico/stdlib.h"
#include "sfe_psram.h"
#include "st7701s.h"
#include <stdio.h>
#include <stdlib.h>
#include <string.h>

#define PSRAM_BASE 0x11000000u
#define PSRAM_CS_PIN 0
#define FB_BYTES ((size_t)SCREEN_WIDTH * SCREEN_HEIGHT * 2)
#define BACKLIGHT_PIN 12

// time
uint32_t hal_get_time_ms(void) { return to_ms_since_boot(get_absolute_time()); }
void hal_delay_ms(uint32_t ms) { sleep_ms(ms); }

// display
// TODO: 18-bit RGB panel via PIO+DMA
static uint16_t *g_fb = NULL;

void hal_display_init(void) {
  stdio_init_all();
  size_t psram = sfe_setup_psram(PSRAM_CS_PIN);
  if (psram >= FB_BYTES)
    g_fb = (uint16_t *)PSRAM_BASE;

  st7701s_init();

  gpio_init(BACKLIGHT_PIN); // TODO: PWM for brightness
  gpio_set_dir(BACKLIGHT_PIN, GPIO_OUT);
  gpio_put(BACKLIGHT_PIN, 1);

  if (g_fb)
    dpi_start(g_fb); // continuous RGB565 scanout (pio2 + dma)
}
uint16_t *hal_get_framebuffer(void) { return g_fb; }
void hal_display_present(void) {}

// audio: I2S to a PCM5102A via pico_audio_i2s (pio0 + dma0). The DAC runs off
// its internal PLL, so MCLK isn't driven (SCK held low).
#define I2S_DATA_PIN 6
#define I2S_CLK_BASE 7 // BCLK=7, LRCLK=8
#define I2S_SCK_PIN 9
#define AUDIO_CHANNELS 2
#define AUDIO_BUF_SAMPLES 1152 // one mp3 frame per channel
#define AUDIO_BUF_COUNT 4

static audio_buffer_pool_t *s_audio_pool = NULL;
static audio_buffer_t *s_audio_cur = NULL;

void hal_audio_init(uint32_t sample_rate) {
  gpio_init(I2S_SCK_PIN);
  gpio_set_dir(I2S_SCK_PIN, GPIO_OUT);
  gpio_put(I2S_SCK_PIN, 0);

  static audio_format_t fmt;
  fmt.sample_freq = sample_rate;
  fmt.format = AUDIO_BUFFER_FORMAT_PCM_S16;
  fmt.channel_count = AUDIO_CHANNELS;

  static audio_buffer_format_t buf_fmt;
  buf_fmt.format = &fmt;
  buf_fmt.sample_stride = AUDIO_CHANNELS * sizeof(int16_t);

  s_audio_pool =
      audio_new_producer_pool(&buf_fmt, AUDIO_BUF_COUNT, AUDIO_BUF_SAMPLES);

  audio_i2s_config_t cfg = {
      .data_pin = I2S_DATA_PIN,
      .clock_pin_base = I2S_CLK_BASE,
      .dma_channel = 0,
      .pio_sm = 0,
  };
  audio_i2s_setup(&fmt, &cfg);
  audio_i2s_connect(s_audio_pool);
  audio_i2s_set_enabled(true);
}

bool hal_audio_ready(void) {
  if (!s_audio_pool)
    return false;
  if (!s_audio_cur)
    s_audio_cur = take_audio_buffer(s_audio_pool, false);
  return s_audio_cur != NULL;
}

void hal_audio_submit(const int16_t *samples, size_t num_samples) {
  if (!s_audio_pool)
    return;
  if (!s_audio_cur) {
    s_audio_cur = take_audio_buffer(s_audio_pool, false);
    if (!s_audio_cur)
      return;
  }
  uint32_t frames = (uint32_t)num_samples / AUDIO_CHANNELS;
  if (frames > s_audio_cur->max_sample_count)
    frames = s_audio_cur->max_sample_count;
  memcpy(s_audio_cur->buffer->bytes, samples,
         frames * AUDIO_CHANNELS * sizeof(int16_t));
  s_audio_cur->sample_count = frames;
  give_audio_buffer(s_audio_pool, s_audio_cur);
  s_audio_cur = NULL;
}

// storage: SD card over PIO SDIO + FatFs (carlk3 library), mounted lazily
static FATFS s_fs;
static bool s_sd_mounted = false;

static bool sd_ensure_mounted(void) {
  if (s_sd_mounted)
    return true;
  FRESULT fr = f_mount(&s_fs, "", 1);
  if (fr != FR_OK) {
    printf("sd: f_mount failed (%d)\n", fr);
    return false;
  }
  s_sd_mounted = true;
  return true;
}

hal_file_t hal_fopen(const char *path, const char *mode) {
  if (!sd_ensure_mounted())
    return NULL;
  BYTE flags = FA_READ;
  if (mode && strchr(mode, 'w'))
    flags = FA_WRITE | FA_CREATE_ALWAYS;
  else if (mode && strchr(mode, 'a'))
    flags = FA_WRITE | FA_OPEN_APPEND;
  FIL *fp = calloc(1, sizeof(FIL));
  if (!fp)
    return NULL;
  if (f_open(fp, path, flags) != FR_OK) {
    free(fp);
    return NULL;
  }
  return (hal_file_t)fp;
}

size_t hal_fread(void *ptr, size_t size, size_t count, hal_file_t file) {
  if (!file || size == 0)
    return 0;
  UINT br = 0;
  if (f_read((FIL *)file, ptr, (UINT)(size * count), &br) != FR_OK)
    return 0;
  return br / size;
}

int hal_fclose(hal_file_t file) {
  if (!file)
    return -1;
  FRESULT fr = f_close((FIL *)file);
  free(file);
  return fr == FR_OK ? 0 : -1;
}

hal_dir_t hal_diropen(const char *path) {
  if (!sd_ensure_mounted())
    return NULL;
  DIR *dp = calloc(1, sizeof(DIR));
  if (!dp)
    return NULL;
  if (f_opendir(dp, path) != FR_OK) {
    free(dp);
    return NULL;
  }
  return (hal_dir_t)dp;
}

bool hal_dirread(hal_dir_t dir, hal_dirent_t *out) {
  if (!dir || !out)
    return false;
  FILINFO fno;
  if (f_readdir((DIR *)dir, &fno) != FR_OK || fno.fname[0] == 0)
    return false;
  snprintf(out->name, sizeof(out->name), "%s", fno.fname);
  out->is_dir = (fno.fattrib & AM_DIR) != 0;
  out->size = (uint32_t)fno.fsize;
  return true;
}

void hal_dirclose(hal_dir_t dir) {
  if (!dir)
    return;
  f_closedir((DIR *)dir);
  free(dir);
}

// --- shared i2c1 bus: TCA9555 button expander + MAX17048 fuel gauge ---
#define I2C_PORT i2c1
#define I2C_SDA 38
#define I2C_SCL 39
#define I2C_BAUD 400000

#define TCA9555_ADDR 0x20 // A2/A1/A0 -> GND
#define BTN_ACTIVE_LOW 1  // pressed pulls the line low

#define BTN_POWER 0   // P00
#define BTN_VOL_UP 9  // P11
#define BTN_VOL_DN 10 // P12
#define BTN_UP 11     // P13
#define BTN_DOWN 12   // P14
#define BTN_LEFT 13   // P15
#define BTN_RIGHT 14  // P16
#define BTN_CENTER 15 // P17

static bool s_i2c_ready = false;

static void i2c_scan(void) {
  for (uint8_t a = 0x08; a < 0x78; a++) {
    uint8_t d;
    if (i2c_read_blocking(I2C_PORT, a, &d, 1, false) >= 0)
      printf("i2c: found device 0x%02X\n", a);
  }
}

static void i2c_bus_init(void) {
  if (s_i2c_ready)
    return;
  i2c_init(I2C_PORT, I2C_BAUD);
  gpio_set_function(I2C_SDA, GPIO_FUNC_I2C);
  gpio_set_function(I2C_SCL, GPIO_FUNC_I2C);
  gpio_pull_up(I2C_SDA);
  gpio_pull_up(I2C_SCL);
  s_i2c_ready = true;
  i2c_scan(); // TODO: remove if it works
}

void hal_input_init(void) { i2c_bus_init(); }

// raw 16-bit expander (port0 = low byte, port1 = high byte); 0xFFFF on error
static uint16_t read_expander(void) {
  uint8_t reg = 0x00, buf[2];
  if (i2c_write_blocking(I2C_PORT, TCA9555_ADDR, &reg, 1, true) < 0)
    return 0xFFFF;
  if (i2c_read_blocking(I2C_PORT, TCA9555_ADDR, buf, 2, false) < 0)
    return 0xFFFF;
  return (uint16_t)buf[0] | ((uint16_t)buf[1] << 8);
}
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

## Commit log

2026-05-12 first pcb draft!
    [audio.kicad_sch, mp3player.kicad_pcb, mp3player.kicad_sch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]
2026-05-14 new journal entry & updated project files!!
    [processing.kicad_sch]
2026-05-16 new day + schematic updates
    [mp3player.kicad_pcb, mp3player.kicad_sch, power.kicad_sch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]
2026-05-16 new journal entry!
    [audio.kicad_sch, mp3player.kicad_sch, power.kicad_sch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]
2026-05-23 progress + new journal entry!
    [audio.kicad_sch, mp3player.kicad_sch, power.kicad_sch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]
2026-05-28 may 28th
    [audio.kicad_sch, mp3player.kicad_sch, power.kicad_sch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]
2026-05-29 more components associations
    [audio.kicad_sch, power.kicad_sch, processing.kicad_sch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]
2026-05-29 may 29th + files updates
    [audio.kicad_sch, mp3player.kicad_pcb, power.kicad_sch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]
2026-05-31 routing + may 30th update + things
    [audio.kicad_sch, mp3player.kicad_pcb, mp3player.kicad_sch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]
2026-05-31 jun 1st what already noo
    [mp3player.kicad_pcb, power.kicad_sch, processing.kicad_sch]
2026-06-01 first of june wo&
    [mp3player.kicad_pcb, processing.kicad_sch]
2026-06-03 new dayy
    [bom.csv, designators.csv, mp3player.kicad_pcb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]
2026-06-04 new day!
    [mp3player.kicad_pcb, processing.kicad_sch]
2026-06-14 pcb updates + journaling
    [mp3player.kicad_pcb, pcb.step, processing.kicad_sch]
2026-06-15 journal & files update
    [mp3player.kicad_pcb, pcb.step]
2026-06-17 june 18th update
    [mp3player.kicad_pcb, pcb.step]
2026-06-19 battery indicator & icon system
2026-06-20 firmware/journal update
    [mp3player.kicad_pcb, processing.kicad_sch]
2026-06-20 readme & journal
    [render.blend]
2026-06-21 cad added + journal/bom update
    [audio.kicad_sch, bom.csv, bottom.step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]
